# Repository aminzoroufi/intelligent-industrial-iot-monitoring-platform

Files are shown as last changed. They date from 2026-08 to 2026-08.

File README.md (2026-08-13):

# Intelligent Industrial IoT Monitoring Platform

> Implementation status: source-complete pre-release demonstrator. Software and
> synthetic evidence are `SIMULATED`; no bench or field verification is claimed.
> Native embedded builds, CAD release checks, post-fix browser evidence, CI on
> GitHub, and publication remain explicit release gates.

A retrofit condition-monitoring demonstrator for a small workshop motor, pump,
or ventilation fan. The system is designed for equipment that is currently
checked manually and where a full SCADA or predictive-maintenance suite would
be disproportionate. It combines temperature, vibration, and DC current
telemetry with offline buffering, Modbus RTU interoperability, deterministic
alarms, and an explainable Isolation Forest comparison.

The reference asset is `motor-01` at site `workshop-demo`. Seeded and simulated
measurements are always labeled as synthetic.

## Architecture

```mermaid
flowchart LR
  S["Sensors and fault fixture"] --> E["ESP32 edge gateway"]
  M["STM32 sensor node"] <-->|"RS-485 / Modbus RTU"| E
  E -->|"Wi-Fi + MQTT"| B["Mosquitto broker"]
  B --> I["Python ingestion service"]
  I --> P[("PostgreSQL")]
  P --> A["FastAPI + anomaly worker"]
  A -->|"REST + authenticated WebSocket"| W["Next.js dashboard"]
```

## Safety boundary

This is a portfolio-grade engineering demonstrator, not a certified safety
controller. Its relay output is limited to a low-voltage demonstration load.
It must not switch mains power or implement an emergency stop, personnel
protection, or unattended safety-critical shutdown. The bench procedure
requires a physical method to remove actuator power.

## Local software demo

Start the local software stack with:

```sh
cp .env.example .env
make demo
make scenario-normal
```

This starts PostgreSQL, Mosquitto, FastAPI, MQTT ingestion, a simulated gateway,
the anomaly worker, and the responsive operator dashboard at
`http://localhost:3000`. The simulated gateway publishes retained health and
safe-state command acknowledgements. ESP32 and STM32 targets, editable Wokwi
projects, Modbus PTY simulation, and the versioned per-device anomaly workflow
are implemented. Python anomaly/Modbus paths pass source and integration tests;
the embedded targets are not compiled in the available environment. The
hardware review package is editable and statically checked but intentionally
un-routed and not released for fabrication because KiCad/FreeCAD execution and
physical evidence are unavailable. Exact evidence and known limits are recorded
in the [verification report](docs/verification-report.md).

Run the local software gates with:

```sh
python -m venv .venv
.venv/bin/pip install -r requirements/ci.lock
npm --prefix web ci
make check
```

The full Compose/API smoke is `make compose-smoke` while the stack is running.
GitHub CI additionally starts a clean stack and runs the desktop/mobile
Playwright happy path.

## Engineering reports

- [English engineering report](docs/report/Intelligent_Industrial_IoT_Monitoring_Platform_EN.pdf)
- [گزارش مهندسی فارسی](docs/report/Intelligent_Industrial_IoT_Monitoring_Platform_FA.pdf)

Both PDFs are generated from editable Markdown sources, use an invariant PDF
build, and pass font/text/page rendering checks plus contact-sheet inspection.
The separate hardware connectivity PDF is marked review-only and is not a
KiCad schematic export or fabrication release.

## Repository map

| Path | Responsibility |
| --- | --- |
| `contracts/` | Versioned MQTT schemas, examples, and topic policy |
| `services/` | FastAPI, MQTT ingestion, and anomaly processes |
| `web/` | Responsive Next.js operator dashboard |
| `firmware/` | ESP32 gateway, STM32 node, shared logic, and host tests |
| `simulator/` | Telemetry, Modbus, Wokwi, and named fault scenarios |
| `hardware/` | KiCad, BOM, fabrication, model provenance, and enclosure |
| `docs/` | Architecture, operation, verification, traceability, and reports |

The dashboard workflows and security boundary are documented in
[`docs/dashboard.md`](docs/dashboard.md).

The repository does not currently include a dashboard screenshot. A previous
browser smoke was observed, but the environment did not permit a new capture
after the live-channel fix; substituting a fabricated or stale image would be
misleading. The committed Playwright flow and GitHub Compose job are the release
path for producing that evidence.

## Verification levels

- `SIMULATED`: demonstrated with host software, test fixtures, or Wokwi.
- `BENCH-VERIFIED`: executed on the documented low-voltage physical bench.
- `FIELD-VALIDATED`: evaluated on real equipment under a controlled protocol.

The current software ingestion and authenticated operations slices are
`SIMULATED`. The ESP32 path is implemented but build-blocked, not verified.
Hardware paths remain explicitly unverified unless physical evidence is
supplied.

## Known limitations and roadmap

The immediate priorities are (1) run ESP-IDF and STM32Cube target builds with
size evidence, (2) migrate and route the board in KiCad 10 and pass native
ERC/DRC before regenerating real fabrication outputs, and (3) run the complete
GitHub CI/Compose/browser flow and capture a truthful dashboard image. The
phased plan and exit criteria are in
[roadmap and limitations](docs/roadmap-and-limitations.md).

## Author and license

Copyright (c) 2026 Amin Zoroufi <aminn.zoroufi@gmail.com>

Source is visible for portfolio inspection under the custom
[Portfolio Source-Available License](LICENSE.md). This is not an open-source
license and it is marked for legal review.

Locked runtime dependency attribution is recorded in the
[dependency/license inventory](docs/dependency-license-inventory.csv).

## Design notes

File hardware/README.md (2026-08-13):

# Hardware design status

Revision `A0-UNVERIFIED` is an editable engineering review package for the
extra-low-voltage demonstrator. It is not fabrication-ready. Do not order a PCB,
assemble it, or connect a load from these files until the review gates in
`fabrication/fabrication-status.json` are completed and independently checked.

The canonical, machine-readable source is `design.json`. It records the board
envelope, selected manufacturer part numbers, ratings, placement, pin/net
intent, safety policy, and which 3D shapes are dimensional engineering envelopes
rather than official component models. Run:

```sh
.venv/bin/python scripts/generate_hardware_artifacts.py
.venv/bin/python scripts/generate_hardware_artifacts.py --check
```

The generator creates the BOM, placement, editable KiCad review sources,
mechanical envelopes, FreeCAD rebuild macro, preview SVGs, and review-only
fabrication files. The generation check verifies metadata and model checksums;
it does not substitute for electrical or layout verification.

## Circuit intent

- 5 V SELV/PELV input through resettable overcurrent, polarity, transient, and
  bulk-decoupling stages;
- AP2112K 3.3 V rail with local bulk and high-frequency decoupling;
- ESP32-WROOM-32E gateway with explicit enable/boot bias and UART header;
- TMP117 temperature, INA219 high-side current, 50 mΩ/1 W shunt, and ADXL345
  SPI vibration sensor with interrupt;
- MAX3485 3.3 V half-duplex RS-485, SM712 clamp, selectable 120 Ω termination,
  optional 680 Ω bias, ground reference, and bus test points;
- AO3400A low-side 5 V relay-coil driver, gate resistor/pull-down, and SS14
  flyback diode;
- relay COM/NO connector restricted by project policy to 30 VDC and 2 A. It
  must never switch mains, implement an emergency stop, or control a hazardous
  load.

## KiCad boundary

`iiot-monitor.kicad_pcb` is an editable KiCad board review placement. The
schematic is deliberately retained in KiCad legacy v4 form with a project cache
library because `kicad-cli` is unavailable here; KiCad 10 must import and save it
as `.kicad_sch`. The board is un-routed. Custom review footprints and every pin
mapping must be replaced or verified against current official datasheets and
manufacturer land patterns.

The checked-in ERC/DRC reports say `NOT RUN` and are not passes. The Gerber-like
review set contains outline/status geometry only; copper production geometry is
intentionally absent. After schematic migration, symbol/footprint review,
routing, and actual zero-unexplained-violation ERC/DRC, regenerate outputs with
KiCad 10.0.4 and replace the reports with raw tool output.

## Mechanical and provenance boundary

The project-authored ESP32 and relay STEP files are only datasheet-sized
engineering envelopes. They are visibly named `-envelope`, recorded with source
URL and checksum in `model-provenance.csv`, and must not be described as vendor
3D models. The board assembly STEP is likewise a placement/clearance envelope,
not a KiCad component-accurate export.

`enclosure/iiot-enclosure.FCMacro` is the editable FreeCAD rebuild source.
Project-generated STEP/STL review geometry uses the same board-derived
dimensions. FreeCAD is unavailable in the current environment, so no `.FCStd`
save or FreeCAD-vs-export comparison is claimed.

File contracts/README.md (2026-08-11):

# MQTT contracts

All application topics use this root:

```text
iiot/v1/{site_id}/{device_id}/telemetry
iiot/v1/{site_id}/{device_id}/health
iiot/v1/{site_id}/{device_id}/events
iiot/v1/{site_id}/{device_id}/commands
iiot/v1/{site_id}/{device_id}/command-acks
iiot/v1/{site_id}/{device_id}/availability
```

`site_id` and `device_id` must match `^[a-z0-9][a-z0-9-]{0,62}$`. Payloads are
UTF-8 JSON and must not exceed 16 KiB. Unknown schema versions, malformed JSON,
oversized payloads, topic/payload identity mismatches, non-finite numbers, and
unknown command kinds are rejected, counted, and recorded without logging
secrets or the complete offending payload.

| Suffix | QoS | Retained | Notes |
| --- | ---: | --- | --- |
| telemetry | 1 | no | duplicates removed by globally unique `message_id` |
| health | 1 | yes | latest bounded snapshot; never contains credentials |
| events | 1 | no | state changes and diagnostics |
| commands | 1 | no | authenticated server origin, short expiry |
| command-acks | 1 | no | one acknowledgement per command attempt |
| availability | 1 | yes | LWT publishes `offline`; successful boot publishes `online` |

## Time and ordering

Timestamps are RFC 3339 UTC. When the device clock is not synchronized,
`device_time` is `null`, `clock_synchronized` is false, and backend receipt time
is the display fallback. The monotonic `sequence` orders messages from one
device across a configuration-preserving reboot. `uptime_ms` may reset and reset
reason is reported in health. No order is assumed across different MQTT topics.

During disconnection, the gateway retains a bounded durable telemetry ring.
Replay is oldest-first with the original `message_id`, `sequence`, and
`device_time`; `replayed` becomes true. If capacity is exhausted, the oldest
telemetry record is dropped, `dropped_message_count` increments, and local
threshold monitoring continues. This deterministic policy preserves the newest
condition evidence while making loss visible.

## Compatibility

Additive optional fields are allowed within version 1. Removing a field,
changing a unit or meaning, relaxing an identity boundary, or changing field
type requires a new schema and topic major version. Consumers ignore unknown
optional properties only when the schema permits them; these schemas otherwise
use `additionalProperties: false` to catch accidental drift.

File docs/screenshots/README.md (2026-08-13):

# Screenshot evidence policy

Only screenshots captured from the running committed application with clearly
labeled synthetic data belong here. Do not add mockups, design-tool renders,
stale pages from an earlier build, or images whose source commit and scenario
cannot be identified.

The release screenshot is pending because the browser rerun after the live
loopback/cookie fix has not executed. The CI Playwright job must first pass the
desktop and mobile operator flow against a clean Compose build. Then capture the
fleet and device-detail views, record the source commit and named simulator
scenario in the image caption or adjacent Markdown, inspect for exposed tokens
or personal data, and add the real image to the README.

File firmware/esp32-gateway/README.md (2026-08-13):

# ESP32 edge gateway

The gateway targets an ESP32-DevKitC V4 with ESP-IDF 6.0.2. It is organized as
fixed-responsibility FreeRTOS tasks around the dependency-free shared C core.
The relay output is for an extra-low-voltage demonstration load only and is OFF
before NVS, networking, or command processing begins.

## Responsibilities and timing

| Responsibility | Implementation | Default behavior |
| --- | --- | --- |
| sampling | high-priority static task | 100 ms period with `vTaskDelayUntil` |
| vibration interrupt | GPIO ISR to task notification | ISR performs no bus work |
| aggregation | static task and `iiot_sample_window_t` | 1 s mean/RMS/peak/crest window |
| local alarms | shared hysteresis state machine | continues without a network |
| communication | MQTT QoS 1 and durable replay | oldest queued record first |
| storage | NVS config, slot records, metadata CRC | 32 records by default |
| commands | bounded MQTT input queue | identity/expiry/type/range validated |
| health | retained MQTT snapshot | every 10 seconds |
| watchdog | ESP task watchdog | sampling/aggregation/communication enrolled |

The ADXL345 data-ready ISR only notifies the sampling task. TMP117 and INA219
share a 400 kHz I2C bus; ADXL345 uses 5 MHz SPI mode 3. A UART in hardware
half-duplex RS-485 mode polls the focused STM32 node. All measurement fields use
the SI units encoded in the version-1 contracts.

## Pin map

| Function | ESP32 GPIO | Direction / interface | Electrical note |
| --- | ---: | --- | --- |
| TMP117 + INA219 SDA | 21 | I2C bidirectional | 3.3 V pull-ups |
| TMP117 + INA219 SCL | 22 | I2C output | 3.3 V pull-ups |
| ADXL345 MOSI / MISO / SCLK | 23 / 19 / 18 | SPI | 3.3 V only |
| ADXL345 chip select | 5 | output | pull high at reset |
| ADXL345 data ready | 34 | interrupt input | input-only GPIO |
| RS-485 TX / RX / DE | 17 / 16 / 25 | UART half duplex | MAX3485-class 3.3 V transceiver |
| demo relay driver | 27 | output | transistor + flyback; low-voltage load only |
| status LED | 2 | output | board-dependent active level |
| provision / reset | 0 | pulled-up input | 10 s boot hold required for erase |

GPIO0 is a strapping pin. Production hardware must keep its pull-up and button
network compatible with normal boot and make the ten-second reset action
deliberate.

## Configuration and provisioning

The NVS blob has a magic value, schema version, structure size, generation, and
CRC-32. Version 0 has an explicit migration function in the shared core. An
invalid blob loads conservative defaults, raises `CONFIG_FALLBACK`, and keeps
the relay OFF. Unprovisioned firmware exposes only a 120-second serial setup
window. Commands are `SHOW`, `SET field=value`, `COMMIT`, and `ABORT`; secret
values are masked in device responses. See `docs/provisioning.md` for the
operator sequence.

NVS does not by itself make stored Wi-Fi credentials confidential. Enable ESP32
Secure Boot, flash encryption, and NVS encryption with per-device provisioning
for any deployment outside the isolated demonstration.

## Offline queue and sequence durability

Payload records occupy separate NVS keys and compact metadata carries a CRC.
One enqueue writes one slot plus metadata, allowing NVS wear levelling to avoid
rewriting a monolithic queue blob. At capacity, the oldest record is replaced,
the dropped counter increments, and `OFFLINE_QUEUE_DROP` remains visible.
Reconnect replays oldest first with the original UUID and sequence and sets
`replayed=true`; a crash between publish and removal can duplicate a message,
which the backend removes by UUID.

Sequence numbers are reserved in NVS blocks of 256. A reboot can create a gap,
but cannot move the sequence backwards, and avoids a flash commit every second.
This remains a bounded demonstration design; the actual write lifetime needs a
bench workload and flash-vendor endurance calculation.

## Build and host tests

```sh
cd firmware/esp32-gateway
idf.py set-target esp32
idf.py build

cmake -S firmware/host-tests -B firmware/host-tests/build
cmake --build firmware/host-tests/build --parallel
ctest --test-dir firmware/host-tests/build --output-on-failure
```

No target or host C build is marked as passed yet because the available macOS
compiler is blocked by its system Xcode license and ESP-IDF is not installed.
The Linux CI workflow must execute these commands before the milestone can move
from implemented to verified.

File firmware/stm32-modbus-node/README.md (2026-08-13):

# STM32 Modbus RTU sensor node

This focused node targets the STM32F103C8T6 Blue Pill supported by Wokwi. It
does not duplicate gateway networking or storage. A timer schedules a
deterministic ADC fixture, USART2 serves the versioned Modbus RTU map through a
MAX3485-class transceiver, and the independent watchdog covers main-loop
stalls. The implementation uses STM32CubeF1 1.8.6 HAL sources from an external,
exact-version checkout rather than copying vendor code into this repository.

## Build

```sh
git clone --recursive --depth 1 --branch v1.8.6 \
  https://github.com/STMicroelectronics/STM32CubeF1.git /path/to/STM32CubeF1
export STM32CUBE_F1_PATH=/path/to/STM32CubeF1
cmake -S firmware/stm32-modbus-node -B firmware/stm32-modbus-node/build \
  -DCMAKE_TOOLCHAIN_FILE=cmake/arm-none-eabi.cmake
cmake --build firmware/stm32-modbus-node/build --parallel
```

The build emits ELF, HEX, BIN, linker map, and an `arm-none-eabi-size` report.
The compiler, CMake, and STM32Cube checkout are unavailable in the current
environment, so none of those outputs or a target build pass is claimed.

## Timing and fault path

TIM3 interrupts at 10 Hz and only marks a sample due. ADC conversion and
calibration execute in the main loop. USART2 uses 115200 baud, 8 data bits,
even parity, and 1 stop bit; receive-to-idle interrupts hand an eight-byte frame
to the main loop. CRC, address, function, range, and value checks happen in the
same dependency-free core exercised by host tests. Incomplete frames are
discarded and reported as a UART fault.

The ADC fixture maps 0–3.3 V to 20.00–100.00 °C before signed offset and Q15 gain
calibration. Readings within ten ADC counts of a rail are marked out of range.
A missing 500 ms sampling deadline raises `SAMPLE_STALE`. The physical build
refreshes a roughly two-second independent watchdog; Wokwi builds explicitly
disable IWDG because that peripheral is not modeled by the simulator.

Configuration occupies the final 1 KiB flash page and carries a magic value,
schema version, structure size, generation, limits, and CRC-32. Writes erase
and verify that one page. An interrupted write loads safe defaults and exposes
the configuration-fallback fault. Reset count uses the backup domain when
available and is explicitly reduced to a simulated value in Wokwi.

## Wiring

| Function | STM32 pin | MAX3485 / fixture connection | Note |
| --- | --- | --- | --- |
| fixture input | PA0 / ADC1_IN0 | 0–3.3 V potentiometer or conditioned sensor | never exceed MCU rails |
| Modbus TX | PA2 / USART2_TX | DI | 3.3 V logic |
| Modbus RX | PA3 / USART2_RX | RO | 3.3 V logic |
| driver enable | PB1 | DE and active-high `/RE` control | receiver disabled while sending |
| status LED | PC13 | onboard LED | active low on common Blue Pill boards |
| SWD | PA13 / PA14 | SWDIO / SWCLK | retain for recovery/debug |

Place 120 Ω termination only at each physical bus end, not every node. Fit one
known bias network for the whole bus, provide a shared reference conductor,
and add connector-side surge/ESD protection appropriate to the installation.
This is a 3.3 V, low-voltage demonstration and is not an isolated industrial
interface until a documented isolated transceiver/power design is used.

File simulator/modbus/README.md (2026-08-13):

# Modbus RTU pseudo-terminal simulator

The simulator exposes the version-1 STM32 register contract through a POSIX
pseudo-terminal pair. The printed slave path can be opened by a host Modbus
master at 115200 baud, 8 data bits, even parity, and 1 stop bit.

```sh
python -m simulator.modbus.pty_node --scenario normal
python -m simulator.modbus.pty_node --scenario timeout
python -m simulator.modbus.pty_node --scenario bad-crc
python -m simulator.modbus.pty_node --scenario illegal-address
python -m simulator.modbus.pty_node --scenario stale
```

The protocol model is deterministic and its first-eight-register response is
the same golden byte frame asserted by the shared C tests. A pseudo-terminal
models byte transport only; it cannot verify MAX3485 voltage levels, driver
enable timing, line bias, termination, common-mode range, reflections, or EMC.

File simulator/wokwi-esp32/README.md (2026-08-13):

# ESP32 Wokwi path

This project selects the ESP32-DevKitC V4 supported by Wokwi and runs the same
gateway tasks and shared C core as the production build. Exact TMP117, INA219,
ADXL345, and RS-485 electrical behavior is not claimed: `CONFIG_IIOT_SIMULATION`
selects a deterministic adapter at the driver boundary while the real register
drivers remain in the source tree.

## Build

With ESP-IDF 6.0.2 exported in the shell:

```sh
cd firmware/esp32-gateway
idf.py set-target esp32
SDKCONFIG_DEFAULTS="sdkconfig.defaults;sdkconfig.simulation" idf.py build
```

Open `simulator/wokwi-esp32/diagram.json` with the Wokwi extension. On first
boot, use the serial console before its 120-second deadline:

```text
SET wifi_ssid=Wokwi-GUEST
SET wifi_password=
SET mqtt_host=host.wokwi.internal
SET mqtt_port=1883
COMMIT
```

`host.wokwi.internal` is appropriate only when the Wokwi environment can reach
a broker forwarded from the development host. Do not point the command topic at
an unauthenticated public broker. The serial flow masks password values in its
responses.

After reboot, each short press of **NEXT SYNTHETIC FAULT** advances through
normal, rising temperature, vibration increase, current overload, temperature
driver failure, and Modbus timeout, then returns to normal. Values are formula
driven, not random. Holding that GPIO during boot for ten seconds intentionally
factory-resets NVS, so do not hold it while resetting unless erasure is desired.

No Wokwi execution is claimed in the current verification report: ESP-IDF and
the Wokwi runner were unavailable in the implementation environment. In
particular, simulator timing, Wi-Fi/RF behavior, flash wear, analog fidelity,
and RS-485 electrical behavior remain unverified by Wokwi.

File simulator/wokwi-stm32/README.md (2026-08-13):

# STM32 Wokwi path

The Blue Pill simulation exercises the 10 Hz timer, ADC fixture, GPIO, USART2,
and shared Modbus state. Build it with:

```sh
export STM32CUBE_F1_PATH=/path/to/STM32CubeF1-v1.8.6
cmake -S firmware/stm32-modbus-node \
  -B firmware/stm32-modbus-node/build-wokwi \
  -DCMAKE_TOOLCHAIN_FILE=cmake/arm-none-eabi.cmake \
  -DIIOT_WOKWI=ON
cmake --build firmware/stm32-modbus-node/build-wokwi --parallel
```

The potentiometer defaults to ADC count 2048 and the logic analyzer observes
USART2 TX, RX, and driver enable. Wokwi documents ADC1 as partial and does not
model the independent watchdog, power controller, RTC/backup domain, MAX3485
electrical layer, line termination, or biasing. The Wokwi build therefore
disables IWDG and uses a simulated reset count; these omissions are explicit.

No Wokwi execution or serial trace is claimed because the runner and ARM
toolchain are unavailable in the current environment.

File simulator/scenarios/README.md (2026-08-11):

# Deterministic scenarios

All scenarios are synthetic and use a fixed pseudo-random seed. `normal` keeps
signals inside the reference envelope. The other named scenarios introduce one
controlled change at a time: temperature ramp, vibration growth, current ramp,
or a stuck temperature value. These are reproducibility fixtures, not evidence
of field performance or mechanical root cause.

Run a scenario against the local broker with:

```sh
.venv/bin/python -m simulator.telemetry_generator.main normal
```

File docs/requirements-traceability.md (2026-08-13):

# Requirements traceability

Status values are `DESIGNED`, `IMPLEMENTED`, `VERIFIED`, and `BLOCKED`. A design
entry is not evidence that a requirement works.

| ID | Requirement | Code / artifact | Verification | Documentation | Status |
| --- | --- | --- | --- | --- | --- |
| SYS-001 | End-to-end MQTT condition telemetry | `contracts/`, `services/`, `web/` | Backend Compose passed; dashboard sign-in/fleet smoke passed; post-fix live browser run blocked | `docs/system-overview.md`, `docs/dashboard.md` | IMPLEMENTED |
| SYS-002 | Safe low-voltage relay command | command schema, API command service, simulated gateway | unit tests plus live ON/OFF MQTT acknowledgements | `docs/safety.md`, `docs/operations-workflows.md` | VERIFIED |
| DAT-001 | Versioned SI-unit telemetry envelope | `contracts/schemas/telemetry.v1.schema.json` | `tests/test_contracts.py` (8 passing) | `contracts/README.md` | VERIFIED |
| DAT-002 | Idempotent ordered replay | `services/api/app/ingestion.py` | unit collision tests and identical Compose batch replay | `contracts/README.md` | VERIFIED |
| ESP-001 | Sensor sampling and aggregation | `firmware/esp32-gateway/`, `firmware/shared/` | C host tests authored; local compiler blocked | `firmware/esp32-gateway/README.md` | IMPLEMENTED |
| ESP-002 | Bounded durable offline queue | NVS slot journal and shared ring core | queue/loss/replay tests authored; local compiler blocked; power interruption unverified | `docs/offline-behavior.md` | IMPLEMENTED |
| STM-001 | Versioned Modbus RTU node | STM32 HAL target plus shared C protocol and PTY simulator | 5 Python PTY/protocol tests pass; C golden/target builds blocked | `docs/modbus-register-map.md`, `firmware/stm32-modbus-node/README.md` | IMPLEMENTED |
| API-001 | JWT authentication and authorization | `services/api/` | auth tests and authenticated Compose query | API OpenAPI schema | VERIFIED |
| API-002 | Device, alarm, calibration, maintenance APIs | `services/api/` | REST integration tests and Compose workflow | OpenAPI and `docs/operations-workflows.md` | VERIFIED |
| UI-001 | Accessible responsive operator workflows | `web/` | ESLint, TypeScript, 4 component tests, production build, partial browser smoke | `docs/dashboard.md` | IMPLEMENTED |
| ML-001 | Explainable per-device Isolation Forest | `services/anomaly_worker/`, model registry/API, dashboard comparison | 8 causal-feature, artifact, evaluation, registry, scoring, and fallback tests pass | `docs/anomaly-detection.md` | VERIFIED |
| HW-001 | Editable KiCad design and fabrication outputs | canonical design, KiCad review source, BOM, placement, mechanical/provenance sources | 5 static consistency/provenance/release-safety tests pass; ERC/DRC and routing blocked | `hardware/README.md`, `docs/hardware-in-the-loop.md` | IMPLEMENTED |
| SIM-001 | Reproducible named software faults | telemetry generator, Wokwi projects, Modbus PTY | Python scenario/Modbus tests; target Wokwi runs blocked | simulator READMEs and verification report | IMPLEMENTED |
| DOC-001 | English and Persian reproducible PDFs | editable sources, invariant report generator, bundled fonts | both 18-page reports and 4-page hardware review render on every page; contact sheets visually inspected | `docs/report/README.md` | VERIFIED |
| CI-001 | Credential-free hosted quality/security gates | `.github/workflows/`, Dependabot config | YAML, action-pin, command, and hygiene inspection pass; hosted execution awaits publication | `docs/ci.md` | IMPLEMENTED |
| LIC-001 | Dependency attribution and incompatible-license gate | runtime/CI locks, npm lock, Python policy, generated inventory | 602 exact rows; missing/unknown/strong-copyleft policy guards pass | `THIRD_PARTY_NOTICES.md`, `docs/ci.md` | VERIFIED |
| PROV-001 | Binary/CAD asset provenance | model and dashboard-font provenance plus license files | checksum, license, release-guard, and source checks pass | `hardware/README.md`, `THIRD_PARTY_NOTICES.md` | VERIFIED |
| SEC-001 | Secrets, malformed input, replay, CSV, WS threat controls | contracts, services, dashboard BFF, ESP32 command/config paths | validation, authorization, replay, CSV, credential-safe WS tests; ESP32 tests build-blocked | `SECURITY.md`, `docs/operations-workflows.md`, `docs/provisioning.md` | IMPLEMENTED |

This table is updated at every milestone. `VERIFIED` requires a corresponding
passing row in `docs/verification-report.md`.

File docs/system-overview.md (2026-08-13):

# System overview

## Problem and users

Workshop maintainers often inspect small motors, pumps, and fans manually. A
bearing problem, overload, blocked cooling path, or failed sensor can emerge
between inspections. The demonstrator provides maintainers with continuous
condition signals without pretending to replace a certified safety system.

Primary stakeholders are a maintenance operator, a calibration technician, a
system administrator, and an engineer evaluating retrofit feasibility.

## Scope

- one ESP32 gateway for temperature, vibration, DC current, local thresholds,
  bounded buffering, MQTT, and a low-voltage demo actuator;
- one focused STM32 sensor node exposing a versioned Modbus RTU register map;
- separate ingestion, API, and anomaly processes backed by PostgreSQL;
- an authenticated browser UI for live condition, alarms, calibration,
  maintenance, export, and detector comparison;
- deterministic host simulation and named fault scenarios.

## Non-goals

- certified protection, emergency stop, or direct mains switching;
- diagnosis of a specific mechanical root cause from synthetic data;
- high-availability cloud operations or multi-tenant billing;
- claiming simulated performance as field performance.

## Success criteria

Success means the seeded MQTT-to-dashboard path is reproducible from a clean
clone; replay is idempotent; alarm and command actions are authenticated and
audited; firmware calculations and Modbus frames are host-tested; anomaly
results are reproducible and explained by observed features; and all remaining
hardware gaps are visible in the verification report.

## System context

```mermaid
flowchart LR
  O["Maintenance operator"] -->|"condition, alarms, records, safe demo command"| P["Monitoring platform"]
  T["Calibration technician"] -->|"calibration evidence"| P
  A["Administrator"] -->|"identity and configuration"| P
  P -->|"temperature, current, vibration"| D["Low-voltage demo asset"]
  P <-->|"legacy register exchange"| L["STM32 Modbus node"]
```

## Container view

```mermaid
flowchart LR
  G["ESP32 or simulated gateway"] -->|"MQTT QoS 1"| M["Mosquitto"]
  M --> I["MQTT ingestor"]
  I --> DB[("PostgreSQL")]
  DB --> ML["Anomaly worker"]
  DB --> API["FastAPI"]
  API -->|"REST + authenticated WebSocket"| UI["Next.js dashboard"]
  UI --> OP["Operator browser"]
```

## Local deployment

```mermaid
flowchart TB
  subgraph H["Developer host"]
    subgraph C["Docker Compose project: iiot-monitoring-demo"]
      PG["postgres:18.3-bookworm"]
      MQ["eclipse-mosquitto:2.1.2-alpine"]
      PY["API / ingestor / anomaly / simulated gateway"]
      WEB["Node 24 / Next.js standalone"]
    end
    B["Browser"] -->|"localhost:3000"| WEB
    WEB -->|"internal HTTP"| PY
    PY <--> PG
    PY <--> MQ
  end
```

Exact tags are selected for reproducibility but are not yet digest-pinned. The
Compose network uses public development credentials and plain MQTT only inside
the local demonstrator boundary.

## Telemetry and live-update sequence

```mermaid
sequenceDiagram
  participant G as Gateway
  participant M as Mosquitto
  participant I as Ingestor
  participant P as PostgreSQL
  participant A as FastAPI
  participant W as Browser
  G->>M: QoS 1 telemetry envelope
  M->>I: deliver topic + payload
  I->>A: bounded internal ingest request
  A->>P: validate and insert or deduplicate
  P-->>A: NOTIFY telemetry event
  A-->>W: authenticated WebSocket update
  W->>A: bounded history request
  A->>P: ordered range query
  P-->>A: persisted rows
  A-->>W: SI-unit telemetry page
```

## Safe relay-command sequence

```mermaid
sequenceDiagram
  participant O as Operator
  participant A as FastAPI
  participant P as PostgreSQL
  participant M as Mosquitto
  participant G as Gateway
  O->>A: authenticated relay request + timeout
  A->>P: audit accepted command
  A->>M: publish device-scoped command
  M->>G: QoS 1 command
  G->>G: validate ID, target, expiry, safe policy
  G->>M: acknowledgement with resulting state
  M->>A: command acknowledgement
  A->>P: durable completion/rejection audit
  A-->>O: live status; relay auto-clears OFF
```

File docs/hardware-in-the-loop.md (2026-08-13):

# Low-voltage hardware-in-the-loop procedure

Status: not executed; no physical hardware was supplied.

This procedure applies only after a reviewed PCB revision has passed ERC, DRC,
assembly inspection, continuity checks, and a current-limited power-up. Revision
`A0-UNVERIFIED` is not eligible.

## Equipment and boundary

- isolated 5 V laboratory supply with adjustable current limit and physical
  output switch;
- oscilloscope, DMM, logic analyzer, and USB-to-3.3 V UART adapter;
- protected low-voltage DC demo load and independent fuse;
- second RS-485 node or isolated USB/RS-485 adapter;
- vibration fixture that cannot eject parts and temperature reference that stays
  within component and handling limits.

Never connect mains. The relay is not an emergency stop, interlock, protective
device, or permission to energize equipment. Keep a physical means to remove
actuator power.

## Ordered checks

1. Inspect polarity, shorts, component orientation, shunt, TVS, flyback diode,
   relay isolation distance, and connector labels with power removed.
2. Measure input-to-ground resistance. Power at 5 V with a 100 mA current limit,
   then raise the limit only after the 3.3 V rail is stable and no part heats.
3. Record 5 V/3.3 V rail min/max during ESP32 Wi-Fi association and relay
   switching; inspect reset reason and brownout counters.
4. Compare TMP117 readings with a traceable reference at three safe points.
   Record raw, previous, and updated calibration coefficients.
5. Apply known DC current through the shunt at zero and at least three load
   points below 2 A. Compare DMM and INA219 values without exceeding shunt power.
6. Check ADXL345 identity, data-ready interrupt rate, stationary noise, axis
   orientation, and response on the guarded vibration fixture.
7. Inspect RS-485 A/B waveforms and DE timing with termination disabled and then
   enabled only at the two bus ends. Exercise valid, CRC-error, exception,
   timeout, and disconnected-node cases.
8. Drive only the fused low-voltage demo relay load. Verify default OFF, command
   expiry, bounded auto-off, flyback behavior, reboot safe state, and MQTT
   acknowledgement for ON/OFF.
9. Disconnect network access long enough to fill/replay the documented queue;
   power-cycle at controlled journal points and check ordering/loss counters.
10. Inject the named firmware scenarios, task stall, and repeated reset. Confirm
    watchdog recovery does not create a reboot loop.

For every run, retain board revision/serial, firmware SHA, equipment IDs,
calibration dates, setup photo, raw measurements, expected tolerances, result,
operator, UTC time, and anomalies. Only actual retained evidence may change a
verification level to `BENCH-VERIFIED`.

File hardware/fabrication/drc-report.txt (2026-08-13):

Status: NOT RUN
Tool: kicad-cli 10.0.4
Reason: tool is unavailable in the execution environment.
This file is not a passing report and must be replaced by actual tool output.

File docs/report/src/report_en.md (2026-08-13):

# Intelligent Industrial IoT Monitoring Platform

Author: Amin Zoroufi
Email: aminn.zoroufi@gmail.com
Configured repository: https://github.com/aminzoroufi/intelligent-industrial-iot-monitoring-platform
Version: 0.1.0
Date: 12 August 2026
Copyright: Copyright 2026 Amin Zoroufi
Verification level: SIMULATED - no bench or field validation is claimed
License: Portfolio Source-Available; custom text remains marked for legal review

## 1. Executive summary

This portfolio system demonstrates continuous condition monitoring for a small workshop motor, pump, or fan. It combines temperature, vibration, and DC current measurements with bounded offline buffering, MQTT transport, PostgreSQL persistence, authenticated operator workflows, Modbus RTU interoperability, and an intentionally modest Isolation Forest comparison detector.

The implementation is evidence-led. Forty-seven Python tests pass after the hardware static checks are included, the dashboard passes lint, strict TypeScript, and four component tests, and a live Compose backend slice previously exercised MQTT ingestion, replay, authentication, WebSocket delivery, alarms, and safe simulated relay acknowledgements. Embedded target builds, current CAD ERC/DRC, post-change Compose execution, physical bench behavior, and field performance remain explicitly unverified.

## 2. Maintenance problem and product rationale

Small workshops often inspect motors and fans manually. Bearing degradation, overload, blocked cooling, loose connections, or a failed sensor can develop between rounds. A full SCADA or predictive-maintenance suite can be disproportionate for one low-value asset, while unreliable connectivity makes a cloud-only design fragile.

The project was chosen because it crosses embedded timing, industrial protocols, backend integrity, operator experience, electronics, and honest data analysis without requiring invented customer claims. The reference asset is the clearly simulated motor-01 at workshop-demo. The intended value is earlier, better documented maintenance attention, not automatic diagnosis or safety shutdown.

## 3. Stakeholders, scope, safety, and success

Stakeholders are the maintenance operator, calibration technician, administrator, and engineer evaluating retrofit feasibility. Use cases include live status, alarm acknowledgement, calibration history, maintenance records, bounded export, offline replay, and comparison of deterministic and statistical detection.

- In scope: one ESP32 gateway, one focused STM32 Modbus node, sensors, a low-voltage demo relay, local Compose services, simulation, and editable engineering sources.
- Out of scope: mains switching, emergency-stop functions, certified protection, autonomous hazardous control, customer deployment, high availability, and field-validated predictive claims.
- Success means reproducible data contracts, idempotent replay, authenticated and audited mutations, explicit health/fault state, host-tested logic, and visible verification gaps.

## 4. Architecture and end-to-end data flow

[[ARCHITECTURE]]

Sensors feed the ESP32 through I2C, SPI with a data-ready interrupt, current measurement, and a UART-controlled MAX3485-class RS-485 interface. The gateway validates, aggregates, sequences, and queues telemetry before publishing versioned MQTT envelopes. A dedicated ingestor validates topic identity and JSON Schema before one transaction persists device state, telemetry, and threshold alarms.

FastAPI exposes authenticated REST and origin-checked WebSockets. PostgreSQL LISTEN/NOTIFY crosses process boundaries without turning the API into the ingestion path. The Next.js dashboard uses a same-origin backend-for-frontend for REST and an HttpOnly cookie for browser WebSocket authentication.

## 5. ESP32 gateway, sensors, and real-time behavior

The ESP-IDF 6.0.2 source separates production drivers from shared C logic. TMP117 and INA219 use I2C; ADXL345 uses SPI and data-ready signaling; RS-485 uses explicit driver-enable timing; a deterministic Wokwi adapter replaces only the driver boundary. FreeRTOS tasks cover acquisition, aggregation, MQTT, commands, health, and fault supervision.

Shared host logic implements configuration magic/schema/generation/CRC, migration and safe defaults, RMS/peak/crest calculations, sample-quality accounting, threshold hysteresis, bounded oldest-drop buffering, topics, serialization, and exponential reconnect with jitter. NVS uses per-slot records plus a pending journal and reserved sequence ranges to survive interruption without silent ordering ambiguity.

The relay defaults OFF, validates device and expiry, auto-clears after a bounded interval, and reports acknowledgement state. Watchdog and reboot-loop guards report reset reasons rather than hiding repeated failure. Target compilation is not claimed because ESP-IDF and a usable host C toolchain were unavailable.

## 6. STM32 node and Modbus RTU

The STM32F103C8T6-class node uses STM32CubeF1 HAL design intent: TIM3 triggers a 10 Hz acquisition fixture, ADC values update a versioned 18-register map, USART2 runs 115200 8E1, and RS-485 DE is explicit. Function 0x03 reads registers; bounded 0x06 writes update permitted configuration and persist a CRC-protected record in the final flash page.

Illegal function, address, value, CRC, timeout, and stale-data cases have explicit outcomes. A watchdog, backup-domain reset count, and fault flags keep operational state inspectable. Five Python tests verify golden bytes, request/response CRC, exception frames, stale registers, timeout, and a pseudo-terminal round trip. The shared C golden tests and ARM target remain build-blocked.

## 7. Provisioning, connectivity, queue, and health

Provisioning is intentionally local: serial commands accept bounded configuration, secrets are never returned, and factory reset requires a deliberate multi-step sequence. Wi-Fi and MQTT reconnect use bounded exponential backoff with jitter. MQTT topics include site, device, and message kind; telemetry uses QoS 1, retained health reports liveness, and LWT marks unexpected disconnects.

When the broker is unavailable, a finite flash queue records exact capacity, depth, dropped-message count, and replay flag. The oldest entry is dropped only when capacity is exhausted, and replay preserves stored order. Clock-unsynchronized samples carry null device time and uptime rather than fabricated UTC. Heartbeats expose RSSI, reset reason/count, firmware, queue state, Modbus state, and active faults.

## 8. Backend data, APIs, authentication, and audit

PostgreSQL stores users, devices, thresholds, telemetry, health snapshots, alarms, calibration, maintenance, commands, audit events, error logs, and anomaly-model registry metadata. Device message ID and device-sequence uniqueness make duplicate delivery idempotent while rejecting conflicting reuse. Monotonic sequence and uptime fields are 64-bit.

FastAPI validates bounded time ranges and payloads, returns explicit errors, escapes CSV formula prefixes, and never leaks artifact paths or secrets. OAuth2 password login issues short-lived audience-bound JWTs. Admin-only mutations create audit events. Browser WebSockets require an exact configured Origin and an HttpOnly cookie; command-line clients use a bearer subprotocol rather than query-string tokens.

## 9. Dashboard and maintenance workflows

The responsive Next.js 16 dashboard provides fleet status, device health, bounded/gapped telemetry charts with SI units and threshold overlays, alarm history and acknowledgement, calibration, maintenance, threshold configuration, CSV export, relay command state, and an About/legal screen. Initial independent requests run in Server Components; interactive controls remain small Client Components.

The detector-comparison route obtains model readiness from the database registry. It separates threshold, sensor-rule, and anomaly sources, reports not-ready/stale/error states, shows model version and training counts, and labels all evaluation metrics synthetic. The production build and browser sign-in/fleet smoke passed before a loopback live-channel fix; the required rebuilt browser rerun was denied, so that exact path remains blocked.

## 10. Anomaly model and honest interpretation

[[DETECTION_METRICS]]

Per-device feature schema version 1 uses a causal trailing window: temperature level/slope/variation, current mean/variation, vibration RMS mean, peak maximum, crest mean, and vibration/current ratio. Training accepts only explicitly selected good-quality, fault-free healthy windows, splits chronologically, fixes seed 20260811, and records schema, library version, interval, counts, policy, and SHA-256 checksum.

The persisted score is the negative of Isolation Forest score_samples, so higher means more anomalous. The percentile is an empirical rank against healthy validation scores, not probability. Reasons cite observed values and healthy 1st/99th percentiles without claiming root cause. Missing, stuck, noisy, impossible, inconsistent, or too-fast sensor values remain deterministic rules.

The seeded report gives model F1 0.7293 and false-positive rate 0.0545; deterministic threshold-plus-sensor F1 is 0.6787 with false-positive rate 0.0. These fixture results cannot be generalized to real equipment.

## 11. Simulation and exact reproduction

The telemetry generator has deterministic normal, rising-temperature, vibration-imbalance, current-overload, and stuck-sensor scenarios. Wokwi projects bind the ESP32 and STM32 production boundaries where supported; the Modbus PTY simulator provides host protocol execution without an electrical bus. Simulator gaps include RF, analog accuracy, interrupt jitter, flash wear, brownout physics, and RS-485 signal integrity.

- Copy .env.example to .env, then run docker compose up --build -d.
- Publish a named scenario with python -m simulator.telemetry_generator.main normal.
- Run Python gates with pytest, Ruff, and strict MyPy; run dashboard lint, typecheck, tests, and build separately.
- Regenerate detector evidence with python -m services.anomaly_worker.main evaluate-demo.

## 12. Schematic, PCB, BOM, models, and enclosure

[[BOARD]]

Hardware revision A0-UNVERIFIED is a review package, not a fabrication release. The canonical design selects ESP32-WROOM-32E, TMP117, INA219 with a 50 mOhm 1 W shunt, ADXL345, MAX3485 with optional 120 ohm termination and 680 ohm bias, SM712 bus protection, AP2112K regulation, and an AO3400A/SS14 relay driver. BOM entries include MPN, rating, package, role, and sourcing warning.

The KiCad board is an un-routed review placement. The legacy schematic must be imported and saved by KiCad 10; custom pins and footprints require official-datasheet review. ERC/DRC say NOT RUN. STEP shapes named envelope are project-authored dimensional clearance shapes, not vendor models. The FreeCAD macro and generated STEP/STL enclosure share a 100 x 70 mm board envelope, but FreeCAD execution and component-accurate board export are not claimed.

## 13. Testing strategy and retained evidence

[[VERIFICATION]]

Testing concentrates on integrity and failure boundaries: contract validation, timestamp consistency, duplicate/collision behavior, alarm hysteresis, authentication, authorization, WebSocket credentials, commands, Modbus bytes, feature leakage, model reproducibility, artifact tamper detection, score direction, fallback, and hardware provenance/release guards.

The host currently passes 47 Python tests with 76.31 percent branch-aware coverage against a 70 percent gate, strict MyPy over 49 product source files, Ruff, hardware static generation checks, dashboard ESLint/TypeScript, and four component tests. Earlier live Compose evidence covers PostgreSQL 18.3, Mosquitto 2.1.2, API, ingestor, simulated gateway, replay, WebSocket, alarms, and relay acknowledgements. A follow-up Compose image and browser run was not executed; no pass is inferred.

## 14. CI, traceability, and quality gates

GitHub Actions workflows define Python lint/type/tests/coverage, dashboard lint/type/tests/build/audit, a clean Compose/API/browser path, report generation/verification, checksum-pinned secret scanning, license policy, and hardware static checks without private credentials or hardware. Third-party actions use full commit SHAs. Hosted jobs are not called passing until the repository is published and they execute. Embedded targets and native CAD remain separate unresolved gates.

Requirements traceability maps each requirement to source, evidence, documentation, and status. The verification report distinguishes PASS, PARTIAL, BLOCKED, NOT RUN, SIMULATED, BENCH-VERIFIED, and FIELD-VALIDATED. A clean CI badge must never be used to imply a physical result.

## 15. Security, privacy, and electrical safety

Local demo credentials are public development values and must be rotated for any other environment. Production needs TLS/WSS, per-device broker credentials or certificates, ACLs, secret management, restricted CORS, backup/retention policy, signed update controls, and a deployment threat review. Telemetry is operational rather than personal, but operators and maintenance notes still require least privilege and retention decisions.

Joblib is a pickle-compatible trusted-artifact format. Only administrator-controlled model roots are acceptable; checksum proves integrity, not authorship. The relay must never switch mains or replace an emergency stop, interlock, personnel protection, or physical isolation. Revision A0-UNVERIFIED must not be fabricated.

## 16. Trade-offs, lessons, limitations, and next steps

The architecture favors explicit contracts and separate processes over a compact monolith; this adds deployment pieces but keeps ingestion, operator API, and model failure independent. Per-device models are less convenient than one global model but make baselines and fallback visible. Bounded queues choose measurable loss over uncontrolled flash growth. An inexpensive two-layer carrier is approachable but demands careful layout and validation.

Credible next steps are to accept/install toolchains, compile both targets with warnings enabled, migrate and route the KiCad design, run ERC/DRC, rebuild FreeCAD outputs, execute all Wokwi scenarios, rerun the changed Compose/dashboard path, assemble a current-limited prototype, retain calibrated bench evidence, and define a controlled field protocol before discussing predictive value.

## 17. Repository map, glossary, references, and appendices

Repository paths are contracts for schemas, services for backend and anomaly processes, web for the dashboard, firmware for ESP32/STM32/shared C, simulator for scenarios and Modbus/Wokwi, hardware for editable review sources, data/demo for versioned synthetic evidence, and docs for ADRs, operations, safety, traceability, and reports.

Glossary: LWT is MQTT Last Will and Testament; QoS is delivery quality of service; RMS is root mean square; CRC is cyclic redundancy check; RTU is Modbus binary serial framing; DE is RS-485 driver enable; ERC/DRC are electrical/design rule checks; SELV/PELV are extra-low-voltage safety classifications.

Primary references and exact verified tool versions are recorded in docs/toolchain-versions.md. Design decisions are in docs/adr. Reproduction details, raw-status boundaries, and command evidence are in docs/verification-report.md, docs/local-development.md, docs/anomaly-detection.md, hardware/README.md, and docs/hardware-in-the-loop.md. The configured GitHub destination is not presented as published until authentication and remote verification succeed.

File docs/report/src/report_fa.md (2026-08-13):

# سکوی هوشمند پایش اینترنت اشیای صنعتی

نویسنده: امین زوروفی
رایانامه: aminn.zoroufi@gmail.com
مخزن پیکربندی شده: https://github.com/aminzoroufi/intelligent-industrial-iot-monitoring-platform
نسخه: ۰.۱.۰
تاریخ: ۲۱ مرداد ۱۴۰۵ برابر با ۱۲ اوت ۲۰۲۶
حق نشر: ۲۰۲۶ امین زوروفی
سطح صحه گذاری: شبیه سازی شده - هیچ ادعای آزمون کارگاهی یا میدانی وجود ندارد
مجوز: منبع در دسترس برای نمونه کار؛ متن سفارشی هنوز نیازمند بررسی حقوقی است

## ۱. چکیده مدیریتی

این سامانه یک نمونه عملی برای پایش پیوسته وضعیت موتور، پمپ یا فن کوچک کارگاهی است. دما، ارتعاش و جریان مستقیم در گره لبه اندازه گیری می شوند؛ داده در قطع شبکه داخل صف محدود نگهداری می شود و سپس با MQTT به پایگاه داده و داشبورد امن می رسد. یک گره Modbus RTU و یک آشکارساز مقایسه ای Isolation Forest نیز مسیر اتصال به تجهیزات قدیمی و تحلیل چندمتغیره را نشان می دهند.

گزارش بر شواهد واقعی مخزن تکیه دارد. با افزودن آزمون های ایستای سخت افزار، ۴۷ آزمون پایتون موفق است و داشبورد نیز آزمون نگارش، نوع سنجی سخت گیرانه و چهار آزمون مؤلفه را می گذراند. اجرای زنده پیشین، دریافت MQTT، بازپخش بدون تکرار، ورود، WebSocket، هشدار و تأیید فرمان رله شبیه سازی شده را پوشش داده است. ساخت هدف های نهفته، ERC و DRC، اجرای پشته تغییر یافته، آزمون فیزیکی و کارایی میدانی هنوز تأیید نشده اند.

## ۲. مسئله نگهداری و دلیل انتخاب پروژه

در یک کارگاه کوچک، بازدید موتور و فن معمولا دوره ای و دستی است. خرابی یاتاقان، اضافه بار، گرفتگی مسیر خنک کاری، اتصال سست یا خرابی حسگر ممکن است میان دو بازدید شکل بگیرد. سامانه کامل SCADA یا نگهداری پیش بینانه برای یک تجهیز کم ارزش می تواند پرهزینه باشد و راهکار فقط ابری نیز در شبکه ناپایدار قابل اتکا نیست.

این مسئله انتخاب شد زیرا زمان بندی نهفته، پروتکل صنعتی، یکپارچگی داده، تجربه اپراتور، الکترونیک و تحلیل صادقانه را در یک محصول منسجم کنار هم قرار می دهد، بی آنکه مشتری یا استقرار واقعی ساخته شود. تجهیز مرجع motor-01 در محل شبیه سازی شده workshop-demo است. هدف، جلب توجه زودتر و مستندتر تعمیرکار است؛ نه تشخیص قطعی یا خاموشی ایمنی خودکار.

## ۳. ذی نفعان، دامنه، ایمنی و معیار موفقیت

کاربران اصلی اپراتور نگهداری، کارشناس کالیبراسیون، مدیر سامانه و مهندس ارزیاب امکان بازسازی هستند. مشاهده وضعیت زنده، تأیید هشدار، ثبت کالیبراسیون و تعمیرات، خروجی محدود، بازپخش آفلاین و مقایسه آشکارساز قطعی و آماری از موارد استفاده اند.

- در دامنه: یک دروازه ESP32، یک گره کوچک STM32 و Modbus، حسگرها، رله نمایشی کم ولتاژ، سرویس های محلی، شبیه سازی و منابع مهندسی ویرایش پذیر.
- بیرون از دامنه: کلیدزنی برق شهر، توقف اضطراری، حفاظت گواهی شده، کنترل خودکار خطرناک، استقرار مشتری، دسترس پذیری بالا و ادعای پیش بینی میدانی.
- موفقیت یعنی قرارداد داده قابل بازتولید، بازپخش idempotent، تغییرات احراز و ممیزی شده، سلامت و خطای آشکار، منطق میزبان آزموده و شکاف های راستی آزمایی قابل مشاهده.

## ۴. معماری و جریان سراسری داده

[[ARCHITECTURE]]

حسگرها از راه I2C، رابط SPI همراه وقفه آماده بودن داده، مسیر اندازه گیری جریان و UART متصل به فرستنده گیرنده RS-485 به ESP32 وصل می شوند. دروازه داده را اعتبارسنجی و تجمیع می کند، شماره ترتیب می دهد، در صف می گذارد و پاکت نسخه دار MQTT را می فرستد. سرویس دریافت، هویت موضوع و JSON Schema را پیش از ثبت تراکنشی دستگاه، تله متری و هشدار آستانه کنترل می کند.

FastAPI رابط REST احراز شده و WebSocket با Origin دقیق فراهم می کند. سازوکار LISTEN و NOTIFY پایگاه PostgreSQL رویداد را میان فرایندها جابه جا می کند. داشبورد Next.js برای REST از واسط هم مبدأ و برای WebSocket مرورگر از کوکی HttpOnly بهره می برد.

## ۵. دروازه ESP32، حسگرها و رفتار بلادرنگ

کد ESP-IDF نسخه ۶.۰.۲ درایور تولیدی را از منطق مشترک C جدا می کند. TMP117 و INA219 روی I2C، حسگر ADXL345 روی SPI و وقفه داده، و MAX3485 روی UART با زمان بندی صریح DE قرار دارند. وظیفه های FreeRTOS نمونه برداری، تجمیع، MQTT، فرمان، سلامت و پایش خطا را جدا می کنند.

منطق میزبان، نسخه و CRC پیکربندی، مهاجرت و مقدار امن، RMS و قله و ضریب تاج، کیفیت نمونه، هیسترزیس، صف محدود با حذف قدیمی ترین رکورد، موضوع و سریال سازی و اتصال مجدد نمایی با jitter را پوشش می دهد. NVS از خانه های مستقل، دفتر رخداد در انتظار و رزرو بازه شماره ترتیب استفاده می کند تا قطع برق ترتیب را پنهان نکند.

رله با وضعیت خاموش آغاز می شود، شناسه و انقضا را بررسی می کند و پس از زمان محدود خودکار خاموش می شود. نگهبان وظیفه و محافظ حلقه راه اندازی دوباره، علت reset را گزارش می کنند. چون ابزار ESP-IDF و زنجیره C قابل استفاده موجود نبود، ساخت هدف ادعا نشده است.

## ۶. گره STM32 و Modbus RTU

طرح STM32F103C8T6 با HAL خانواده STM32CubeF1 از TIM3 برای تحریک نمونه ۱۰ هرتز استفاده می کند. داده ADC در نقشه نسخه دار ۱۸ ثبات قرار می گیرد، USART2 با 115200 8E1 کار می کند و DE گذرگاه RS-485 صریح است. تابع 0x03 ثبات ها را می خواند و نوشتن محدود 0x06 فقط پیکربندی مجاز را با CRC در صفحه پایانی فلش نگه می دارد.

تابع، نشانی، مقدار، CRC، timeout و داده کهنه پاسخ روشن دارند. نگهبان، شمارنده reset و پرچم خطا وضعیت را قابل بررسی می کنند. پنج آزمون پایتون بایت های طلایی، CRC، پاسخ استثنا، کهنگی، timeout و رفت و برگشت شبه پایانه را تأیید می کنند؛ ساخت C و هدف ARM همچنان مسدود است.

## ۷. راه اندازی، ارتباط، صف و سلامت دستگاه

راه اندازی عمدا محلی است: فرمان سریال مقدارهای محدود را می پذیرد، رازها را بازنمی گرداند و بازنشانی کارخانه ای به توالی چندمرحله ای نیاز دارد. اتصال دوباره Wi-Fi و MQTT از backoff نمایی محدود همراه jitter پیروی می کند. موضوع MQTT شامل محل، دستگاه و نوع پیام است؛ تله متری QoS 1 دارد، سلامت retained است و LWT قطع غیرمنتظره را نشان می دهد.

در نبود کارگزار، صف محدود فلش ظرفیت، عمق، تعداد حذف و پرچم بازپخش را ثبت می کند. تنها پس از پر شدن، قدیمی ترین پیام حذف می شود و ترتیب ذخیره در بازپخش حفظ می گردد. نمونه بدون ساعت همگام به جای زمان ساختگی، زمان دستگاه null و uptime دارد. heartbeat توان سیگنال، علت و شمار reset، نسخه، صف، Modbus و خطاهای فعال را نمایش می دهد.

## ۸. داده پشتی، API، احراز هویت و ممیزی

PostgreSQL کاربر، دستگاه، آستانه، تله متری، سلامت، هشدار، کالیبراسیون، تعمیرات، فرمان، ممیزی، خطا و رجیستری مدل را نگه می دارد. یکتایی شناسه پیام و زوج دستگاه و ترتیب، تحویل تکراری را بی اثر و استفاده متعارض از ترتیب را رد می کند. ترتیب و uptime از عدد ۶۴ بیتی استفاده می کنند.

FastAPI بازه زمان و ورودی را محدود می کند، خطای صریح می دهد، آغاز خطرناک سلول CSV را خنثی می سازد و مسیر فایل مدل یا راز را منتشر نمی کند. ورود OAuth2 توکن JWT کوتاه عمر و audience دار می دهد. تغییرات مدیر رویداد ممیزی می سازند. WebSocket مرورگر Origin دقیق و کوکی HttpOnly می خواهد و ابزار خط فرمان توکن را در subprotocol می فرستد، نه در نشانی URL.

## ۹. داشبورد و گردش کار نگهداری

داشبورد واکنش گرا وضعیت ناوگان، سلامت دستگاه، نمودار محدود با گسست و واحد SI، خط آستانه، تاریخچه و تأیید هشدار، کالیبراسیون، تعمیرات، آستانه، CSV، فرمان رله و صفحه حقوقی را فراهم می کند. درخواست های مستقل نخست در Server Component هم زمان اجرا می شوند و کنترل تعاملی در Client Component کوچک می ماند.

صفحه مقایسه آشکارساز، آمادگی مدل را از رجیستری می خواند. منبع threshold، sensor_rule و anomaly جداست و وضعیت آماده نبودن، کهنگی و خطا دیده می شود. نسخه مدل، شمار آموزش و معیارهای شبیه سازی شده نمایش داده می شوند. ساخت تولیدی و آزمون مرورگر ورود و ناوگان پیش از اصلاح نام loopback موفق بود؛ بازسازی لازم پس از اصلاح اجازه اجرا نگرفت و آن مسیر هنوز مسدود است.

## ۱۰. مدل ناهنجاری و تفسیر صادقانه

[[DETECTION_METRICS]]

نسخه ۱ ویژگی ها از پنجره علّی دنباله رو استفاده می کند: سطح و شیب و پراکندگی دما، میانگین و پراکندگی جریان، میانگین RMS ارتعاش، بیشینه قله، ضریب تاج و نسبت ارتعاش به جریان. آموزش فقط بازه سالم انتخاب شده با کیفیت خوب و بدون پرچم خطا را می پذیرد، تقسیم زمانی دارد، seed برابر 20260811 است و طرح، نسخه کتابخانه، بازه، شمار و checksum را ثبت می کند.

امتیاز ذخیره شده منفی score_samples است؛ پس مقدار بزرگ تر ناهنجارتر است. percentile رتبه تجربی میان امتیازهای اعتبارسنجی سالم است و احتمال نیست. دلیل، مقدار مشاهده شده و صدک یک و نود و نه سالم را بیان می کند و علت مکانیکی نمی سازد. نبودن، گیرکردن، نویز، بازه ناممکن، ناسازگاری و نرخ بیش از حد حسگر همچنان قانون قطعی اند.

در داده بذری، F1 مدل 0.7293 و نرخ مثبت کاذب 0.0545 است؛ F1 آستانه همراه قانون حسگر 0.6787 و نرخ مثبت کاذب آن صفر است. این اعداد فقط مقایسه روی fixture مصنوعی اند.

## ۱۱. شبیه سازی و بازتولید دقیق

مولد تله متری سناریوهای عادی، افزایش دما، عدم تعادل ارتعاش، اضافه جریان و حسگر گیرکرده را با seed ثابت می سازد. پروژه های Wokwi مرز درایور ESP32 و STM32 را در بخش های پشتیبانی شده جایگزین می کنند و شبیه ساز PTY بدون گذرگاه برقی Modbus را می آزماید. وفاداری آنالوگ، RF، jitter وقفه، فرسایش فلش، brownout و کیفیت الکتریکی RS-485 شبیه سازی نمی شوند.

- فایل .env.example را به .env کپی کنید و docker compose up --build -d را اجرا کنید.
- سناریوی نام دار را با python -m simulator.telemetry_generator.main normal منتشر کنید.
- آزمون های پایتون، Ruff، MyPy و سپس lint و typecheck و test و build داشبورد را جدا اجرا کنید.
- گزارش آشکارساز را با python -m services.anomaly_worker.main evaluate-demo بازسازی کنید.

## ۱۲. شماتیک، برد، BOM، مدل و محفظه

[[BOARD]]

سخت افزار A0-UNVERIFIED بسته بازبینی است و اجازه ساخت ندارد. طرح ESP32-WROOM-32E، TMP117، INA219 و شنت ۵۰ میلی اهم ۱ وات، ADXL345، MAX3485 با termination اختیاری ۱۲۰ اهم و bias برابر ۶۸۰ اهم، حفاظت SM712، رگولاتور AP2112K و درایور رله AO3400A و SS14 را انتخاب می کند. BOM شماره قطعه سازنده، درجه، پکیج، نقش و هشدار تأمین دارد.

برد KiCad فقط چیدمان مسیربندی نشده است. شماتیک قدیمی باید در KiCad 10 وارد و ذخیره شود و پایه و footprint با دیتاشیت رسمی بررسی گردد. ERC و DRC اجرا نشده اند. فایل STEP با نام envelope فقط حجم مهندسی ساخته پروژه است، نه مدل سازنده. ماکروی FreeCAD و STEP و STL از ابعاد برد ۱۰۰ در ۷۰ میلی متر استفاده می کنند، ولی اجرای FreeCAD و خروجی دقیق قطعات ادعا نمی شود.

## ۱۳. راهبرد آزمون و شواهد نگهداری شده

[[VERIFICATION]]

آزمون بر مرز خطا و یکپارچگی متمرکز است: قرارداد، سازگاری زمان، تکرار و برخورد، هیسترزیس، احراز و مجوز، اعتبار WebSocket، فرمان، بایت Modbus، نشت زمانی ویژگی، بازتولید مدل، دستکاری artifact، جهت امتیاز، fallback و حفاظت انتشار سخت افزار.

میزبان اکنون ۴۷ آزمون پایتون با پوشش شاخه ای ۷۶٫۳۱ درصد در برابر دروازه ۷۰ درصد، MyPy سخت گیرانه روی ۴۹ فایل محصول، Ruff، بررسی ایستای سخت افزار، ESLint و TypeScript و چهار آزمون داشبورد را می گذراند. شاهد زنده پیشین PostgreSQL، Mosquitto، API، ingestor، دروازه شبیه سازی شده، بازپخش، WebSocket، هشدار و تأیید رله را پوشش می دهد. اجرای دوباره تصویر Compose و مرورگر انجام نشده است و نتیجه ای از آن استنباط نمی شود.

## ۱۴. CI، ردیابی و دروازه کیفیت

گردش های GitHub Actions دروازه lint و type و test و coverage پایتون، آزمون و build و audit داشبورد، مسیر پاک Compose و API و مرورگر، بازسازی گزارش، جستجوی راز با checksum ثابت، سیاست مجوز و آزمون ایستای سخت افزار را تعریف می کنند. Action بیرونی با SHA کامل قفل است. تا انتشار مخزن و اجرای میزبان، CI موفق ادعا نمی شود و هدف نهفته و CAD بومی همچنان دروازه جدا و حل نشده اند.

جدول ردیابی هر نیازمندی را به منبع، شاهد، سند و وضعیت پیوند می دهد. گزارش راستی آزمایی میان PASS، PARTIAL، BLOCKED، NOT RUN، SIMULATED، BENCH-VERIFIED و FIELD-VALIDATED فرق می گذارد. سبز شدن CI به معنی نتیجه فیزیکی نیست.

## ۱۵. امنیت، حریم خصوصی و ایمنی برق

اعتبارهای نمونه محلی عمومی اند و در هر محیط دیگر باید تعویض شوند. استقرار واقعی TLS و WSS، اعتبار جدا برای دستگاه، ACL کارگزار، مدیر راز، CORS محدود، نسخه پشتیبان، سیاست نگهداری، کنترل به روزرسانی امضا شده و بازبینی تهدید می خواهد. تله متری شخصی نیست، ولی هویت اپراتور و یادداشت تعمیرات به حداقل دسترسی نیاز دارد.

Joblib قالبی سازگار با pickle و فقط برای artifact مورد اعتماد است. checksum یکپارچگی را می سنجد، نه نویسنده را. رله هرگز نباید برق شهر را کلید بزند یا جای توقف اضطراری، interlock، حفاظت انسان یا جداسازی فیزیکی را بگیرد. نسخه A0-UNVERIFIED نباید ساخته شود.

## ۱۶. بده بستان، آموخته ها، محدودیت و گام بعد

معماری قرارداد صریح و فرایند جدا را به monolith کوچک ترجیح می دهد؛ اجزای استقرار بیشتر می شوند، اما خطای دریافت، API و مدل از هم جدا می ماند. مدل هر دستگاه از مدل سراسری دشوارتر است، ولی baseline و fallback را شفاف می کند. صف محدود، اتلاف قابل اندازه گیری را به رشد بی کنترل فلش ترجیح می دهد. برد دولایه ارزان است، اما طرح و آزمون دقیق می خواهد.

گام معتبر بعدی نصب ابزارها، ساخت هر دو هدف با هشدار سخت، مهاجرت و مسیربندی KiCad، ERC و DRC، بازسازی FreeCAD، اجرای سناریوهای Wokwi، اجرای دوباره Compose و داشبورد تغییر یافته، مونتاژ نمونه با محدودکننده جریان، ثبت شاهد کالیبره کارگاهی و تعریف پروتکل میدانی پیش از هر سخن درباره پیش بینی است.

## ۱۷. نقشه مخزن، واژه نامه، منابع و پیوست

مسیر contracts قراردادها، services سرویس و مدل، web داشبورد، firmware کد ESP32 و STM32 و C مشترک، simulator سناریو و Modbus و Wokwi، hardware منبع بازبینی ویرایش پذیر، data/demo شاهد مصنوعی نسخه دار و docs تصمیم، عملیات، ایمنی، ردیابی و گزارش را نگه می دارد.

واژه نامه: LWT پیام آخر MQTT، QoS کیفیت تحویل، RMS ریشه میانگین مربع، CRC کنترل افزونگی چرخه ای، RTU قاب باینری Modbus، DE فعال ساز فرستنده RS-485، ERC و DRC کنترل قانون الکتریکی و طراحی، و SELV یا PELV رده ولتاژ بسیار پایین ایمن است.

نسخه ابزار و منبع رسمی در docs/toolchain-versions.md و تصمیم ها در docs/adr آمده اند. روش بازتولید و مرز شاهد در docs/verification-report.md، docs/local-development.md، docs/anomaly-detection.md، hardware/README.md و docs/hardware-in-the-loop.md قرار دارد. مقصد GitHub تا پیش از احراز و کنترل remote به عنوان مخزن منتشر شده معرفی نمی شود.

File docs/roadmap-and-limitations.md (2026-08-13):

# Roadmap and known limitations

## Current release boundary

The repository is a software-complete, simulated engineering demonstrator. It
is not a V1 fabrication or field release. The API, ingestion, dashboard source,
detectors, telemetry/Modbus simulators, shared embedded logic, reports, and
review hardware artifacts are implemented. The verification report is the
authority for executed evidence.

Known gaps are deliberately not hidden:

- the ESP32 ESP-IDF target has not been compiled, measured, or run in Wokwi;
- the STM32 ARM target has not been compiled or run in Wokwi;
- the carrier is intentionally un-routed and the stored ERC/DRC reports say
  `NOT RUN`; current Gerber-like files are review artifacts, not build data;
- engineering-envelope STEP shapes are not component-accurate vendor models;
- no physical bench, environmental, EMC, isolation, endurance, or field data
  exists;
- the fixed live browser channel still needs a rebuilt Compose/Playwright run
  and a real screenshot;
- the GitHub workflows are source-validated locally but cannot pass until a
  repository is published and the hosted jobs actually execute;
- exact container tags are selected, but immutable image digests are a future
  supply-chain hardening step;
- the custom source-available license remains marked for legal review.

## Phase 1 — toolchain closure

Run shared C tests on Linux CI, compile ESP-IDF 6.0.2 with a size report, and
compile STM32CubeF1 1.8.6 with the pinned ARM toolchain. Run both Wokwi projects
and retain normal, sensor-fault, reconnect/replay, watchdog, CRC, and timeout
serial evidence. Exit when failures and skips are zero or explicitly waived by
a dated engineering decision.

## Phase 2 — native ECAD/MCAD and bench

Import the review schematic into KiCad 10, replace custom review constructs
with validated library items, complete the power/return/RS-485 layout, inspect
creepage and connector clearances, and pass ERC/DRC without unexplained waivers.
Use official vendor/KiCad models where licenses and part identity are verified,
then export the actual board STEP and regenerate the FreeCAD enclosure. Build
one extra-low-voltage prototype and execute the HIL guide with a directly
accessible actuator-power disconnect.

## Phase 3 — release and measured evaluation

Publish the pre-release, let CI run the clean Compose and desktop/mobile browser
flow, capture a source-traceable dashboard screenshot, and pin deployment image
digests. Collect a reviewed healthy baseline and named controlled faults from
the bench; report confidence intervals and false alarms without promoting the
result to field validation. Field validation requires a separate protocol,
site authorization, qualified safety review, and enough representative
operating time to support the claim.

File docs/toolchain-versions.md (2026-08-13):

# Toolchain versions

Version selection was checked on 2026-08-11 against the linked primary project
sources. Patch versions are locked in their owning manifests or container
references; this table records the architecture baseline.

| Tool | Selected line | Verification source | Rationale |
| --- | --- | --- | --- |
| Python | 3.14.6 | https://www.python.org/downloads/release/python-3146/ | Current stable maintenance release |
| FastAPI | 0.141.1 | https://pypi.org/project/fastapi/ | Current non-prerelease package |
| Pydantic | 2.13.4 | https://pypi.org/project/pydantic/ | Current non-prerelease package |
| SQLAlchemy | 2.0.51 | https://pypi.org/project/SQLAlchemy/ | Current stable 2.0 release; 2.1 was beta |
| psycopg | 3.3.4 | https://pypi.org/project/psycopg/ | Current non-prerelease package |
| Paho MQTT | 2.1.0 | https://pypi.org/project/paho-mqtt/ | Maintained MQTT v5-capable release |
| scikit-learn | 1.9.0 | https://pypi.org/project/scikit-learn/ | Current non-prerelease package |
| Node.js | 24.15.0 | https://nodejs.org/en/about/previous-releases | Active LTS container runtime |
| Next.js | 16.2.12 | https://nextjs.org/blog | Active LTS security release; 16.3 is preview |
| React | 19.2.8 | https://www.npmjs.com/package/react | Exact dashboard runtime lock |
| Mosquitto | 2.1.2 (`2.1.2-alpine` image) | https://mosquitto.org/blog/ and https://hub.docker.com/_/eclipse-mosquitto/tags | Current bug-fix release and exact published official image tag |
| PostgreSQL | 18.3 (`18.3-bookworm` image) | https://www.postgresql.org/developer/roadmap/ and https://hub.docker.com/_/postgres | Current supported major/minor before the scheduled 2026-08-13 update |
| ESP-IDF | 6.0.2 | https://docs.espressif.com/projects/esp-idf/en/stable/esp32/get-started/index.html | Current stable documentation and exact component constraint; target build not yet executed |
| STM32CubeF1 | 1.8.6 | https://www.st.com/en/embedded-software/stm32cubef1.html | Current STM32F1 package selected for an external exact-tag checkout; target build not yet executed |
| KiCad | 10.0.4 | https://www.kicad.org/blog/ | Current stable bug-fix release |
| ReportLab | 4.4.9 | https://pypi.org/project/reportlab/ | Exact reproducible PDF generator lock |
| pip-audit | 2.10.1 | https://pypi.org/project/pip-audit/ | Exact CI vulnerability-audit tool |
| Gitleaks | 8.30.1 | https://github.com/gitleaks/gitleaks/releases/tag/v8.30.1 | Exact binary and Linux x64 SHA-256 pinned in CI |
| `actions/checkout` | 7.0.1 | https://github.com/actions/checkout/releases/tag/v7.0.1 | Full release commit pinned in workflows |
| `actions/setup-python` | 7.0.0 | https://github.com/actions/setup-python/releases/tag/v7.0.0 | Full immutable release commit pinned in workflows |
| `actions/setup-node` | 7.0.0 | https://github.com/actions/setup-node/releases/tag/v7.0.0 | Full immutable release commit pinned in workflows |
| `actions/upload-artifact` | 7.0.1 | https://github.com/actions/upload-artifact/releases/tag/v7.0.1 | Full release commit pinned in workflows |

All Python runtime and JavaScript transitive versions and license expressions
are recorded in `docs/dependency-license-inventory.csv`. Container tags are
exact, but their immutable registry digests are not yet locked and remain a
documented supply-chain improvement. A version is not called verified here
solely because it is familiar; each entry has a dated primary source. GitHub
Action and security-tool selections were rechecked on 2026-08-12.

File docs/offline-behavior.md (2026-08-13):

# Offline monitoring and ordered replay

The ESP32 continues sensor sampling, aggregation, deterministic threshold
tracking, watchdog service, and health/fault accounting while MQTT or Wi-Fi is
unavailable. New telemetry enters a bounded NVS-backed ring. The default is 32
one-second records; the allowed capacity is 1–32 records so storage consumption
and recovery time remain bounded.

When full, the queue drops exactly one oldest record before adding the newest.
It increments a persistent dropped-message counter and raises
`OFFLINE_QUEUE_DROP`. This favors recent condition evidence while making loss
observable. It is not lossless historian storage.

After reconnect, the communication task publishes the oldest queued record at
QoS 1 before newer records. It preserves message UUID, sequence, measurement,
quality, fault, device time, and uptime fields, changing only `replayed` to
`true`. A record is removed after the MQTT library accepts it for delivery. A
reset at that boundary can republish it, so backend UUID uniqueness is the final
idempotency control. Per-device sequence numbers order records; no ordering is
assumed across devices or MQTT topics.

The retry delay starts at one second, doubles to a 30-second cap, and adds up to
20 percent bounded jitter. A network disconnect forces the low-voltage relay
OFF. Flash-wear lifetime, RF reconnection timing, and behavior during real
brownouts require bench verification; Wokwi cannot establish them.

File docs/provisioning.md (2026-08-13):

# Provisioning and configuration recovery

Provisioning is deliberately local and time-limited. An unprovisioned ESP32
keeps the demo relay OFF and accepts serial input for 120 seconds. Connect a
3.3 V USB/UART interface with the board powered from its documented low-voltage
supply, open the configured console baud rate, and enter one setting per line:

```text
SHOW
SET site_id=workshop-demo
SET device_id=motor-01
SET wifi_ssid=<local SSID>
SET wifi_password=<local password>
SET mqtt_host=<private broker address>
SET mqtt_port=1883
SET sample_interval_ms=100
SET telemetry_interval_ms=1000
COMMIT
```

Plain MQTT port 1883 is only for the isolated local demonstration. A deployment
should use TLS, broker authentication or client certificates, per-device ACLs,
encrypted NVS/flash, and a protected commissioning channel. Do not paste a
production credential into logs, screenshots, issue reports, or this
repository.

`SHOW` masks the Wi-Fi password. `COMMIT` succeeds only after identifier,
endpoint, timing, queue, threshold, hysteresis, schema, and CRC validation. A
timeout or `ABORT` changes nothing. The operator reboots to re-enter the window.

## Factory reset

Remove power from the demonstration actuator first. Hold the provision/reset
button continuously while resetting the ESP32. The device announces that reset
is armed; releasing the button cancels it. Only a continuous ten-second hold
erases the project's NVS namespace and restarts in the unprovisioned safe state.
The action erases Wi-Fi/MQTT settings, sequence reservation metadata, queue
records, and reset counters. It does not erase unrelated devices or host data.

## Corruption and migration

The version-1 configuration contains a schema version and CRC-32. A valid
version-0 public settings structure has an explicit migration path. Unknown,
truncated, or checksum-invalid data is not partially trusted: conservative
defaults load, `CONFIG_FALLBACK` is reported, networking requires provisioning,
and the relay stays OFF. There is no automatic remote factory reset command.

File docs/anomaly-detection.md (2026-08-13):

# Anomaly detection and model lifecycle

The anomaly subsystem is a comparison detector, not a safety controller and not
a prediction of remaining useful life. Deterministic threshold hysteresis,
sensor-quality flags, impossible-range checks, rate checks, missing data, and
stuck/noisy sensor rules remain authoritative whether or not a statistical model
is ready.

## Causal feature schema

Feature schema version 1 uses a trailing 12-sample window, requires at least six
finite samples, and resets across gaps longer than 30 seconds. No future sample
is used.

| Feature | Unit / interpretation |
| --- | --- |
| temperature level | °C at the current sample |
| temperature slope | °C/min from the causal window |
| temperature variation | population standard deviation in °C |
| current mean and variation | A |
| vibration RMS mean | m/s² |
| vibration peak maximum | m/s² |
| crest-factor mean | dimensionless ratio |
| vibration/current ratio | m/s²/A, denominator bounded away from zero |

Training windows accept only complete `quality=good` telemetry with no fault
flags. A window containing one rejected sample is excluded in full. This is an
explicit healthy-baseline policy, not an assumption that all historical data is
healthy.

## Training and registry

Select and review a healthy window using UTC `received_at` timestamps, then run:

```sh
docker compose exec anomaly-worker python -m services.anomaly_worker.main train \
  --device-id motor-01 \
  --start 2026-08-11T08:00:00Z \
  --end 2026-08-11T09:00:00Z
```

The default gate requires 200 feature rows. Data is split chronologically into
training and validation portions; the estimator uses 200 trees, contamination
`0.02`, one worker, and fixed seed `20260811`. A deterministic model version is
derived from the device, selected interval, schema, contamination, and seed.

The artifact is stored under `IIOT_MODEL_ROOT` and registered in PostgreSQL with
its feature schema, interval, row counts, library version, SHA-256 checksum, and
last-scored time. The API exposes registry metadata at
`GET /api/v1/devices/{device_id}/anomaly-model` but never exposes the internal
artifact path.

Model files are serialized with Joblib. That format can execute code while
loading, so the model root is an administrator-controlled trust boundary: never
place uploaded or untrusted model files there. The worker resolves registry
paths beneath the configured root, verifies the adjacent artifact checksum,
cross-checks it against PostgreSQL, and requires exact feature-schema and
scikit-learn versions before loading.

## Scoring, explanations, and fallback

The raw score is `-IsolationForest.score_samples`, so larger values are more
anomalous. The displayed percentile is the empirical rank against healthy
validation scores. It is not a probability or calibrated confidence.

An explanation identifies up to two features outside the healthy training
window's 1st/99th percentiles, with value and unit. If the estimator detects an
unusual multivariate combination without a univariate tail, the reason says so
without inventing a mechanical diagnosis.

The model states are:

- `model_not_ready`: no registered model; rules continue and a rate-limited
  diagnostic is persisted;
- `ready`: checksum/schema/version checks passed and scoring is enabled;
- `stale`: the artifact exceeds `IIOT_MODEL_STALE_AFTER_DAYS`; retraining is
  required and statistical scoring stops;
- `error`: path, metadata, checksum, or compatibility validation failed; rules
  continue and the failure is visible.

Statistical alarms use source `anomaly`. Independent sensor-rule alarms use
source `sensor_rule`. Threshold alarms keep source `threshold`, so operators can
distinguish all three.

## Reproducible synthetic evaluation

Regenerate the versioned report with:

```sh
.venv/bin/python -m services.anomaly_worker.main evaluate-demo
```

The checked-in evidence is
[`data/demo/anomaly-evaluation.v1.json`](../data/demo/anomaly-evaluation.v1.json).
It contains confusion counts, precision, recall, F1, false-positive rate, and
first detection delay for deterministic normal, temperature, vibration,
current, and stuck-sensor fixtures. The current synthetic Isolation Forest
result is F1 `0.7293` with false-positive rate `0.0545`; the deterministic
threshold-plus-sensor result is F1 `0.6787` with false-positive rate `0.0`.

These numbers compare two algorithms on a seeded fixture. They are not bench or
field performance, do not establish a maintenance interval, and must not be
generalized to real equipment without a separately documented validation
protocol.

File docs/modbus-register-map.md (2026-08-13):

# STM32 Modbus RTU register map

Protocol version 1 uses slave address 1 by default, 115200 baud, 8E1, and
standard Modbus CRC-16 (polynomial representation `0xA001`, low CRC byte first).
Function `0x03` reads holding registers; `0x06` writes only the explicitly
writable configuration registers. Multi-register writes and broadcast writes
are not supported.

| Address | Name | Access | Encoding / unit |
| ---: | --- | --- | --- |
| 0 | map version | R | `0x0100` = v1.0 |
| 1 | product identity | R | `0x4949` (`II`) |
| 2 | node address | R/W | 1–247; takes effect after echoed response |
| 3 | firmware version | R | `0x0001` = 0.1 |
| 4 | sensor status | R | 0 good, 1 stale, 2 out of range, 3 ADC error |
| 5 | fault flags | R | bit 0 config fallback, bit 1 ADC range, bit 2 stale, bit 3 UART |
| 6 | fixture temperature | R | signed 0.01 °C |
| 7 | ADC raw | R | 0–4095 counts |
| 8–9 | uptime | R | unsigned 32-bit milliseconds, high word first |
| 10–11 | reset count | R | unsigned 32-bit, high word first |
| 12 | CRC error count | R | low 16 bits |
| 13 | exception count | R | low 16 bits |
| 14–15 | config generation | R | unsigned 32-bit, high word first |
| 16 | calibration offset | R/W | signed 0.01 °C, −5000 to +5000 |
| 17 | calibration gain | R/W | unsigned Q1.15, 16384–65535 |

Reads must request 1–18 registers wholly inside the map. Illegal function,
address, and value exceptions use codes `0x01`, `0x02`, and `0x03`; a flash
persistence failure uses `0x04`. A bad CRC, wrong slave address, incomplete
frame, or timeout receives no RTU response.

## Golden frames

Read registers 0–7 from node 1:

```text
request:  01 03 00 00 00 08 44 0C
response: 01 03 10 01 00 49 49 00 01 00 01 00 00 00 00 10 9A 08 00 A4 0A
```

The response fixture represents 42.50 °C, ADC count 2048, good status, and no
fault flags. Both the C host suite and the executed Python pseudo-terminal suite
assert the exact bytes. Only the Python suite has run in the current environment.

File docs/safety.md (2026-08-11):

# Electrical and operational safety boundary

The reference setup is extra-low-voltage DC only. The relay output is a demo
actuator and is not a safety interlock.

- Never connect the PCB, relay contacts, or measurement front end directly to
  mains voltage.
- Use a current-limited, isolated bench supply appropriate to the selected DC
  motor and board ratings.
- Place a clearly labeled, directly accessible switch in series with actuator
  power so the operator can remove energy without software.
- Power down before altering wiring. Verify polarity and current-shunt ratings.
- Keep rotating parts guarded and secure the motor to a stable fixture.
- Treat temperature and vibration fault injection as controlled demonstrations;
  do not intentionally damage equipment.
- Relay firmware boots OFF, commands expire quickly, and loss of communication
  never energizes the output.

Any move beyond the documented bench requires an electrical, mechanical,
cybersecurity, and functional-safety assessment by qualified people.

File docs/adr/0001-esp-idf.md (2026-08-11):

# ADR 0001: ESP-IDF for the edge gateway

Status: accepted — 2026-08-11

ESP-IDF is selected for the ESP32 gateway because it exposes FreeRTOS tasks,
hardware timers, interrupts, NVS, watchdogs, networking, and build-time target
configuration without concentrating the system in an Arduino loop. Sensor,
queue, threshold, and serialization logic will remain behind C interfaces so it
can run in host tests. The cost is greater setup complexity and target-specific
build tooling, which is justified by the real-time and fault-handling scope.

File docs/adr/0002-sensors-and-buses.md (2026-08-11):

# ADR 0002: Sensor and interface selection

Status: accepted — 2026-08-11

The gateway uses a TMP117 temperature sensor and INA219 DC current monitor over
I2C, an ADXL345 accelerometer over SPI with a data-ready interrupt, UART with a
MAX3485-class transceiver for RS-485, and GPIO for the low-voltage relay and
status signals. These parts provide explicit digital interfaces, realistic
register-level production drivers, and a credible low-voltage retrofit demo.
Simulation adapters may replace the electrical device only at compile time and
must preserve units, range, status, and deterministic fault controls.

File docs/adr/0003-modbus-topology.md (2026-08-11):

# ADR 0003: Focused STM32 Modbus RTU sensor node

Status: accepted — 2026-08-11

The ESP32 is the single Modbus RTU master and one STM32F103C8T6-class node is a
slave on a half-duplex 3.3 V RS-485 link. This demonstrates legacy industrial
interoperability without duplicating the gateway. Function codes 0x03 and 0x06
cover versioned measurement reads and constrained configuration writes. The
node validates CRC, address, register range, and timing and returns standard
exception responses.

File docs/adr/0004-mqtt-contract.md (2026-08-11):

# ADR 0004: Versioned MQTT topics and QoS

Status: accepted — 2026-08-11

Topics are rooted at `iiot/v1/{site_id}/{device_id}`. Telemetry, events,
commands, and acknowledgements use QoS 1 so duplicates are expected and removed
by `message_id`. Health uses QoS 1 and may be retained; availability uses a
retained QoS 1 last-will state. Command payloads include an ID and short expiry.
No ordering is assumed across topics, while per-device sequence numbers expose
gaps and replay order within telemetry.

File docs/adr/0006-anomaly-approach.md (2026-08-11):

# ADR 0006: Isolation Forest as a comparison detector

Status: accepted — 2026-08-11

Deterministic sensor-quality rules and threshold hysteresis remain authoritative
for impossible values and configured bounds. A per-device Isolation Forest
provides a modest comparison using rolling temperature, current, vibration, and
crest-factor features. It is reproducible, handles multivariate outliers, and
does not require invented fault labels. Its score is not a probability; the UI
will show raw score, healthy-baseline percentile, evidence-based reasons, model
metadata, and fallback state.

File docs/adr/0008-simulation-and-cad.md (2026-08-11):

# ADR 0008: Deterministic simulation and editable CAD

Status: accepted — 2026-08-11

Host fixtures and Wokwi provide repeatable fault scenarios while production
drivers retain actual register behavior. KiCad 10 is the editable ECAD source
and FreeCAD is the editable enclosure source. Generated artifacts are retained
only when reproducible from those sources. Every 3D model requires provenance;
an unavailable vendor model is represented only by a clearly labeled,
datasheet-sized engineering envelope. Simulation cannot validate analog
fidelity, RF, flash wear, interrupt jitter, or RS-485 electrical margins.

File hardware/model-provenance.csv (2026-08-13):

file | applies_to | kind | source | source_url | license | retrieval_date | sha256
hardware/3d-models/ESP32-WROOM-32E-envelope.step | U1 | project-authored engineering envelope | Espressif ESP32-WROOM-32E datasheet mechanical drawing | https://www.espressif.com/sites/default/files/documentation/esp32-wroom-32e_esp32-wroom-32ue_datasheet_en.pdf | Project-authored dimensional envelope; not a manufacturer 3D model | 2026-08-11 | 8dfe89b64b9a9bf211ac3bcaa9603d4f150bf74e338393edfc726469232ce121
hardware/3d-models/G5V-1-envelope.step | K1 | project-authored engineering envelope | Omron G5V-1 datasheet mechanical drawing | https://components.omron.com/us-en/datasheet_pdf/J044-E1.pdf | Project-authored dimensional envelope; not a manufacturer 3D model | 2026-08-11 | 8dcb7da90c5e471939062638f15b5547c81d13b8951bad45b5528ef4da03992c

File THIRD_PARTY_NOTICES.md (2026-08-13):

# Third-Party Notices

Third-party packages and container images remain under their own licenses. The
committed `docs/dependency-license-inventory.csv` records all 602 exact Python
runtime and JavaScript lockfile rows, license expressions, scope, and review
disposition. `requirements/python-license-policy.csv` is the reviewed Python
policy input; JavaScript license metadata comes from `web/package-lock.json`.

Core technologies selected at the architecture baseline include ESP-IDF
(Apache-2.0), STM32Cube components (their applicable ST terms), Mosquitto
(EPL-2.0 or EDL-1.0), PostgreSQL (PostgreSQL License), Python (PSF-2.0),
FastAPI (MIT), SQLAlchemy (MIT), Pydantic (MIT), scikit-learn (BSD-3-Clause),
Next.js (MIT), and React (MIT). This summary is informational; exact locked
versions and transitive licenses take precedence.

No third-party binary CAD model is committed. The STEP files named `-envelope`
are project-authored dimensional shapes and their provenance is recorded in
`hardware/model-provenance.csv`.

`docs/report/fonts/NotoSansArabic-Regular.ttf` and
`NotoSansArabic-Bold.ttf` are from the Noto Arabic project, copyright 2022 The
Noto Project Authors, and are distributed under the SIL Open Font License 1.1.
The required copyright and complete license are preserved in
`docs/report/fonts/OFL.txt`. The fonts are embedded into the Persian PDF.

`web/app/fonts/geist-latin.woff2` and `geist-mono-latin.woff2` are unmodified
Geist subsets bundled by the exact locked Next.js 16.2.12 package. Geist is
copyright 2024 The Geist Project Authors and distributed under the SIL Open
Font License 1.1. The required copyright, complete license, source package,
retrieval date, and SHA-256 checksums are preserved in `web/app/fonts/OFL.txt`
and `web/app/fonts/provenance.csv`. They are self-hosted so the dashboard build
does not fetch fonts from a third-party service.

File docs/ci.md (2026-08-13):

# Continuous integration and dependency policy

The CI workflow has four independent gates: Python/contracts/docs/hardware,
dashboard, shared firmware host tests, and the full Compose/browser path. The
security workflow audits both lock files, validates the committed license
inventory, and scans complete Git history with a checksum-pinned Gitleaks
binary. Neither workflow needs private credentials or physical hardware.

Every `uses:` reference is pinned to a full Git commit. The selected releases
were checked against their official GitHub release pages on 2026-08-12:

- `actions/checkout` 7.0.1;
- `actions/setup-python` 7.0.0;
- `actions/setup-node` 7.0.0;
- `actions/upload-artifact` 7.0.1.

Dependabot proposes action updates monthly. A maintainer must read the upstream
release notes, review permission/runtime changes, replace the full SHA and
version comment together, and let all gates pass. Floating major tags are not
accepted.

Python dependency changes require an exact pin in `requirements/runtime.lock`
or `requirements/ci.lock` and a reviewed row in
`requirements/python-license-policy.csv`. The CI lock includes the runtime lock
and fully pins its additional development/documentation graph. JavaScript
changes must be made through `package-lock.json`. Refresh the public inventory
with:

```bash
.venv/bin/python scripts/check_dependency_licenses.py --write
```

The policy rejects absent/unknown licenses and strong-copyleft expressions that
have not received an explicit licensing decision. `reviewed` rows are not legal
advice; they record the engineering distribution decision and preservation
obligations. The project license does not replace any dependency license.

CI compiles only the hardware-independent C core. ESP-IDF, STM32Cube/ARM, KiCad
ERC/DRC, FreeCAD execution, bench tests, and field tests remain separate named
gates and must never be inferred from a green hosted workflow.

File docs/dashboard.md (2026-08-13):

# Operator dashboard

The Next.js dashboard is a responsive operator surface for the simulated
condition-monitoring stack. It is served at `http://localhost:3000` by the
Compose `web` service and uses UTC consistently in displayed timestamps.

## Workflows

- fleet overview with online, degraded, and offline status text plus color;
- device detail with retained health, current measurements, bounded live and
  historical charts, explicit gaps, SI units, and threshold overlays;
- active and historical alarms with acknowledgement state;
- audited threshold, calibration, and maintenance changes;
- short-lived low-voltage demonstration relay commands with separate accepted,
  completed, rejected, and timed-out states;
- bounded CSV export;
- deterministic-threshold versus anomaly-model comparison driven by the model
  registry, with explicit not-ready, ready, stale, and error states plus the
  versioned synthetic metric/scenario report;
- About/legal content with authorship, source license, verification level, and
  safety boundary.

## Authentication boundary

The browser sends credentials only to the dashboard's same-origin login route.
The server-side route exchanges them with FastAPI and stores the resulting JWT
in an HttpOnly, SameSite=Strict cookie. Dashboard REST requests use an explicit
allow-listing backend-for-frontend; browser code does not read or persist the
token. Non-GET proxy requests reject a mismatched Origin when one is present.

Live updates connect directly to FastAPI because a WebSocket upgrade cannot be
proxied through a Next.js route handler. FastAPI requires an exact allowed
browser Origin and authenticates the upgrade from the same host-only HttpOnly
cookie. For local access, the client normalizes `localhost`, `127.0.0.1`, and
`::1` to the hostname of the dashboard page so the cookie scope stays aligned.
Production must use HTTPS/WSS, set `IIOT_COOKIE_SECURE=true`, and replace the
development origins and secrets.

## Rendering and data limits

Initial page reads happen in Server Components and independent requests run in
parallel. Interactive controls are isolated in Client Components. The live
chart retains at most 240 points in browser memory, creates discontinuous SVG
paths for missing samples, labels axes and units, and shows warning/critical
thresholds. Anomaly markers appear only for persisted scored rows; a model
score is never presented as a probability. The comparison route separately
shows threshold alarms, persisted model readiness, recently returned scored
rows, confusion-derived synthetic metrics, and detection delay.

## Verification boundary

ESLint, strict TypeScript compilation, four Vitest component tests, and the
Next.js production build pass. The build now self-hosts checksum-tracked Geist
subsets under SIL OFL 1.1 and succeeds without a Google Fonts request. An
earlier npm audit reported zero vulnerabilities; the latest local rerun could
not reach the registry, so CI must produce the current audit evidence. A prior
browser smoke passed sign-in, fleet rendering, console inspection, and desktop
overflow inspection. The required container rebuild and browser rerun after
the loopback normalization fix were not executed, so the cookie-authenticated
live path is recorded as blocked until it actually runs.

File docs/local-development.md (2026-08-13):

# Local software development

## Prerequisites

- Docker Engine with Compose v2;
- Python 3.12 through 3.14 for host tools;
- a virtual environment populated with `pip install -r requirements/ci.lock`;
- Node.js 24 with `npm ci --prefix web` when running dashboard checks on the
  host.

## Start the backend vertical slice

```sh
cp .env.example .env
make demo
make demo-status
```

If the host's `make` executable is unavailable, the equivalent start command is
`docker compose up --build -d` after creating `.env`; inspect it with
`docker compose ps`.

The seven-service slice starts PostgreSQL, Mosquitto, the API, the MQTT ingestor,
the anomaly worker, a clearly simulated gateway, and the dashboard. Open the dashboard at
`http://localhost:3000`; the API is served on `http://localhost:8000`, OpenAPI
on `/docs`, Mosquitto on localhost port 1883, and PostgreSQL on localhost port
5432. These published ports are for local development only.

The seeded credentials are `demo-admin` and the password shown explicitly in
`.env.example`. They are intentionally public development values, are never a
production recommendation, and must be changed outside the local demo.

## Publish synthetic telemetry

```sh
make scenario-normal
make scenario-temperature
make scenario-vibration
make scenario-current
make scenario-stuck
```

Every line emitted by the generator includes `"synthetic": true`. Reusing the
same scenario session and sequence range intentionally exercises idempotency.

## Exercise authenticated operations

Use the interactive OpenAPI page to obtain a token, inspect fleet state,
acknowledge alarms, record calibration or maintenance, update thresholds, and
issue the demo relay command. The simulated gateway publishes retained health,
starts with its relay state OFF, rejects expired or mismatched commands, and
returns command acknowledgements through MQTT.

The dashboard signs in through its same-origin backend-for-frontend and keeps
the access token in an HttpOnly, SameSite=Strict cookie. Browser JavaScript
cannot read the token. Its direct WebSocket connection is accepted only when
the request Origin exactly matches `IIOT_CORS_ORIGINS`; the API authenticates
the handshake from the HttpOnly cookie. Command-line clients without a browser
Origin can instead offer `bearer` and the access token as WebSocket
subprotocols. Tokens must never be placed in the WebSocket URL because request
URLs are commonly logged. See `docs/operations-workflows.md` for both flows.

## Train and inspect the anomaly comparison

First publish enough normal samples for the default 200-feature-row gate and
review the interval before declaring it healthy:

```sh
.venv/bin/python -m simulator.telemetry_generator.main normal \
  --count 260 --sequence-start 10000 --session-id anomaly-baseline
docker compose exec postgres psql -U iiot_demo -d iiot_demo -c \
  "select min(received_at), max(received_at), count(*) from telemetry where device_id='motor-01';"
make anomaly-train START=2026-08-11T08:00:00Z END=2026-08-11T09:00:00Z
```

Replace the example timestamps with the reviewed query result. The continuously
running worker will score eligible backlog and new rows. The detector-comparison
dashboard shows `MODEL NOT READY`, `READY`, `STALE`, or `ERROR` from the registry
rather than inferring readiness from UI state. See `docs/anomaly-detection.md`.

The reproducible report does not need database credentials:

```sh
.venv/bin/python -m services.anomaly_worker.main evaluate-demo
```

## Quality gate and bounded cleanup

```sh
make check
make clean-demo
```

The exact quality commands behind `make check` are listed in
`docs/verification-report.md` and can be run directly when a host toolchain
prevents Make from starting.

`make clean-demo` removes only containers and the network in the named
`iiot-monitoring-demo` Compose project. `make reset-demo` additionally removes
only that project's PostgreSQL, Mosquitto, and anomaly-model named volumes.

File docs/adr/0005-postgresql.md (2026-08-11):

# ADR 0005: PostgreSQL persistence

Status: accepted — 2026-08-11

PostgreSQL is selected for transactional device and maintenance workflows,
unique constraints for ingestion idempotency, time-range indexes, JSON metadata
where schemas evolve, and repeatable Alembic migrations. SQLite is restricted
to fast unit tests because concurrency, timestamp, and constraint behavior can
differ. Integration and migration evidence must use PostgreSQL.

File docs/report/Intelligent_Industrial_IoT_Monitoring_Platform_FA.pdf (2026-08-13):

# سکوی هوشمند پایش اینترنت اشیای صنعتی

## گزارش مهندسی نمونه کار

نویسنده: امین زوروفی
: aminn.zoroufi@gmail.com | رایانامه
: https://github.com/aminzoroufi/intelligent-industrial-iot-monitoring-platformشده | پیکربندی | مخزن
نسخه۰.۱.۰ :
تاریخ۲۱ : مرداد ۱۴۰۵ برابر با ۱۲ اوت ۲۰۲۶ حق نشر۲۰۲۶ : امین زوروفی
سطح صحه گذاری: شبیه سازی شده - هیچ ادعای آزمون کارگاهی یا میدانی وجود ندارد مجوز: منبع در دسترس برای نمونه کار؛ متن سفارشی هنوز نیازمند بررسی حقوقی است

فقط نمایش کم ولتاژ؛ فاقد گواهی ایمنی، کارگاهی یا میدانی

صفحه 1 شبیه سازی شده - فاقد اعتبار میدانی

سکوی هوشمند پایش اینترنت اشیای صنعتی

# ۱. چکیده مدیریتی

این سامانه یک نمونه عملی برای پایش پیوسته وضعیت موتور، پمپ یا فن کوچک کارگاهی است. دما، ارتعاش و جریان مستقیم در گره لبه اندازه گیری می شوند؛ داده در قطع شبکه داخل صف محدود نگهداری می شود و سپس با MQTT به پایگاه داده و داشبورد امن می رسد. یک گره RTU Modbus و یک آشکارساز مقایسه ای Forest Isolation نیز مسیر اتصال به تجهیزات قدیمی و تحلیل چندمتغیره را نشان می دهند. گزارش بر شواهد واقعی مخزن تکیه دارد. با افزودن آزمون های ایستای سخت افزار، ۴۷ آزمون پایتون موفق است و داشبورد نیز آزمون نگارش، نوع سنجی سخت گیرانه و چهار آزمون مؤلفه را می گذراند. اجرای زنده پیشین، دریافت MQTT، بازپخش بدون تکرار، ورود، WebSocket، هشدار و تأیید فرمان رله شبیه سازی شده را پوشش داده است. ساخت هدف های نهفته، ERC و DRC، اجرای پشته تغییر یافته، آزمون فیزیکی و کارایی میدانی هنوز تأیید نشده اند.

صفحه 2 شبیه سازی شده - فاقد اعتبار میدانی

# ۲. مسئله نگهداری و دلیل انتخاب پروژه

در یک کارگاه کوچک، بازدید موتور و فن معمولا دوره ای و دستی است. خرابی یاتاقان، اضافه بار، گرفتگی مسیر خنک کاری، اتصال سست یا خرابی حسگر ممکن است میان دو بازدید شکل بگیرد. سامانه کامل SCADA یا نگهداری پیش بینانه برای یک تجهیز کم ارزش می تواند پرهزینه باشد و راهکار فقط ابری نیز در شبکه ناپایدار قابل اتکا نیست. این مسئله انتخاب شد زیرا زمان بندی نهفته، پروتکل صنعتی، یکپارچگی داده، تجربه اپراتور، الکترونیک و تحلیل صادقانه را در یک محصول منسجم کنار هم قرار می دهد، بی آنکه مشتری یا استقرار واقعی ساخته شود. تجهیز مرجع -01motor در محل شبیه سازی شده demo-workshop است. هدف، جلب توجه زودتر و مستندتر تعمیرکار است؛ نه تشخیص قطعی یا خاموشی ایمنی خودکار.

صفحه 3 شبیه سازی شده - فاقد اعتبار میدانی

# ۳. ذی نفعان، دامنه، ایمنی و معیار موفقیت

کاربران اصلی اپراتور نگهداری، کارشناس کالیبراسیون، مدیر سامانه و مهندس ارزیاب امکان بازسازی هستند. مشاهده وضعیت زنده، تأیید هشدار، ثبت کالیبراسیون و تعمیرات، خروجی محدود، بازپخش آفلاین و مقایسه آشکارساز قطعی و آماری از موارد استفاده اند. در دامنه: یک دروازه 32ESP، یک گره کوچک 32STM و Modbus، حسگرها، رله نمایشی کم ولتاژ، سرویس های محلی، شبیه سازی و منابع مهندسی ویرایش پذیر.
بیرون از دامنه: کلیدزنی برق شهر، توقف اضطراری، حفاظت گواهی شده، کنترل خودکار خطرناک، استقرار مشتری، دسترس پذیری بالا و ادعای پیش بینی میدانی.
موفقیت یعنی قرارداد داده قابل بازتولید، بازپخش idempotent، تغییرات احراز و ممیزی شده، سلامت و خطای آشکار، منطق میزبان آزموده و شکاف های راستی آزمایی قابل مشاهده.

صفحه 4 شبیه سازی شده - فاقد اعتبار میدانی

# ۴. معماری و جریان سراسری داده

API و داشبورد دریافت و داده کارگزار MQTT لبه 32ESP حسگرها

Modbus و STM32

WebSocket و UART - MQTT - SQL - REST و I2C و : SPIصریح | مرزهای
شکل ۱. معماری سراسری بر پایه مرزهای پیاده سازی شده مخزن. حسگرها از راه C2I، رابط SPI همراه وقفه آماده بودن داده، مسیر اندازه گیری جریان و UART متصل به فرستنده گیرنده -485RS به 32ESP وصل می شوند. دروازه داده را اعتبارسنجی و تجمیع می کند، شماره ترتیب می دهد، در صف می گذارد و پاکت نسخه دار MQTT را می فرستد. سرویس دریافت، هویت موضوع و Schema JSON را پیش از ثبت تراکنشی دستگاه، تله متری و هشدار آستانه کنترل می کند. FastAPI رابط REST احراز شده و WebSocket با Origin دقیق فراهم می کند. سازوکار LISTEN و NOTIFY پایگاه PostgreSQL رویداد را میان فرایندها جابه جا می کند. داشبورد js.Next برای REST از واسط هم مبدأ و برای WebSocket مرورگر از کوکی HttpOnly بهره می برد.

صفحه 5 شبیه سازی شده - فاقد اعتبار میدانی

# ۵. دروازه 32ESP، حسگرها و رفتار بلادرنگ

کد IDF-ESP نسخه ۶.۰.۲ درایور تولیدی را از منطق مشترک C جدا می کند117TMP . و 219INA روی C2I، حسگر 345ADXL روی SPI و وقفه داده، و 3485MAX روی UART با زمان بندی صریح DE قرار دارند. وظیفه های FreeRTOS نمونه برداری، تجمیع، MQTT، فرمان، سلامت و پایش خطا را جدا می کنند. منطق میزبان، نسخه و CRC پیکربندی، مهاجرت و مقدار امن، RMS و قله و ضریب تاج، کیفیت نمونه، هیسترزیس، صف محدود با حذف قدیمی ترین رکورد، موضوع و سریال سازی و اتصال مجدد نمایی با jitter را پوشش می دهدNVS . از خانه های مستقل، دفتر رخداد در انتظار و رزرو بازه شماره ترتیب استفاده می کند تا قطع برق ترتیب را پنهان نکند. رله با وضعیت خاموش آغاز می شود، شناسه و انقضا را بررسی می کند و پس از زمان محدود خودکار خاموش می شود. نگهبان وظیفه و محافظ حلقه راه اندازی دوباره، علت reset را گزارش می کنند. چون ابزار IDF-ESP و زنجیره C قابل استفاده موجود نبود، ساخت هدف ادعا نشده است.

صفحه 6 شبیه سازی شده - فاقد اعتبار میدانی

Modbus RTU و STM32 گره ۶.

طرح 6T8C103F32STM با HAL خانواده 1CubeF32STM از 3TIM برای تحریک نمونه ۱۰ هرتز استفاده می کند. داده ADC در نقشه نسخه دار ۱۸ ثبات قرار می گیرد، 2USART با 1E8 115200 کار می کند و DE گذرگاه -485RS صریح است. تابع 03x0 ثبات ها را می خواند و نوشتن محدود 06x0 فقط پیکربندی مجاز را با CRC در صفحه پایانی فلش نگه می دارد. تابع، نشانی، مقدار، CRC، timeout و داده کهنه پاسخ روشن دارند. نگهبان، شمارنده reset و پرچم خطا وضعیت را قابل بررسی می کنند. پنج آزمون پایتون بایت های طلایی، CRC، پاسخ استثنا، کهنگی، timeout و رفت و برگشت شبه پایانه را تأیید می کنند؛ ساخت C و هدف ARM همچنان مسدود است.

صفحه 7 شبیه سازی شده - فاقد اعتبار میدانی

# ۷. راه اندازی، ارتباط، صف و سلامت دستگاه

راه اندازی عمدا محلی است: فرمان سریال مقدارهای محدود را می پذیرد، رازها را بازنمی گرداند و بازنشانی کارخانه ای به توالی چندمرحله ای نیاز دارد. اتصال دوباره Fi-Wi و MQTT از backoff نمایی محدود همراه jitter پیروی می کند. موضوع MQTT شامل محل، دستگاه و نوع پیام است؛ تله متری 1 QoS دارد، سلامت retained است و LWT قطع غیرمنتظره را نشان می دهد. در نبود کارگزار، صف محدود فلش ظرفیت، عمق، تعداد حذف و پرچم بازپخش را ثبت می کند. تنها پس از پر شدن، قدیمی ترین پیام حذف می شود و ترتیب ذخیره در بازپخش حفظ می گردد. نمونه بدون ساعت همگام به جای زمان ساختگی، زمان دستگاه null و uptime دارد. heartbeat توان سیگنال، علت و شمار reset، نسخه، صف، Modbus و خطاهای فعال را نمایش می دهد.

صفحه 8 شبیه سازی شده - فاقد اعتبار میدانی

# ۸. داده پشتی، API، احراز هویت و ممیزی

PostgreSQL کاربر، دستگاه، آستانه، تله متری، سلامت، هشدار، کالیبراسیون، تعمیرات، فرمان، ممیزی، خطا و رجیستری مدل را نگه می دارد. یکتایی شناسه پیام و زوج دستگاه و ترتیب، تحویل تکراری را بی اثر و استفاده متعارض از ترتیب را رد می کند. ترتیب و uptime از عدد ۶۴ بیتی استفاده می کنند.
FastAPI بازه زمان و ورودی را محدود می کند، خطای صریح می دهد، آغاز خطرناک سلول CSV را خنثی می سازد و مسیر فایل مدل یا راز را منتشر نمی کند. ورود 2OAuth توکن JWT کوتاه عمر و audience دار می دهد. تغییرات مدیر رویداد ممیزی می سازندWebSocket . مرورگر Origin دقیق و کوکی HttpOnly می خواهد و ابزار خط فرمان توکن را در subprotocol می فرستد، نه در نشانی .URL

صفحه 9 شبیه سازی شده - فاقد اعتبار میدانی

# ۹. داشبورد و گردش کار نگهداری

داشبورد واکنش گرا وضعیت ناوگان، سلامت دستگاه، نمودار محدود با گسست و واحد SI، خط آستانه، تاریخچه و تأیید هشدار، کالیبراسیون، تعمیرات، آستانه، CSV، فرمان رله و صفحه حقوقی را فراهم می کند. درخواست های مستقل نخست در Component Server هم زمان اجرا می شوند و کنترل تعاملی در Component Client کوچک می ماند. صفحه مقایسه آشکارساز، آمادگی مدل را از رجیستری می خواند. منبع threshold، rule_sensor و anomaly جداست و وضعیت آماده نبودن، کهنگی و خطا دیده می شود. نسخه مدل، شمار آموزش و معیارهای شبیه سازی شده نمایش داده می شوند. ساخت تولیدی و آزمون مرورگر ورود و ناوگان پیش از اصلاح نام loopback موفق بود؛ بازسازی لازم پس از اصلاح اجازه اجرا نگرفت و آن مسیر هنوز مسدود است.

صفحه 10 شبیه سازی شده - فاقد اعتبار میدانی

# ۱۰. مدل ناهنجاری و تفسیر صادقانه

قواعد

P 100.0 | R 51.4 | F1 67.9 | FPR 0.0

Isolation Forest

P 97.7 | R 58.2 | F1 72.9 | FPR 5.5

معیار داده مصنوعی - نه احتمال و نه کارایی میدانی

شکل ۲. مقایسه بازتولیدپذیر آشکارسازها در گزارش مصنوعی نسخه دار. نسخه ۱ ویژگی ها از پنجره علّی دنباله رو استفاده می کند: سطح و شیب و پراکندگی دما، میانگین و پراکندگی جریان، میانگین RMS ارتعاش، بیشینه قله، ضریب تاج و نسبت ارتعاش به جریان. آموزش فقط بازه سالم انتخاب شده با کیفیت خوب و بدون پرچم خطا را می پذیرد، تقسیم زمانی دارد، seed برابر 20260811 است و طرح، نسخه کتابخانه، بازه، شمار و checksum را ثبت می کند. امتیاز ذخیره شده منفی samples_score است؛ پس مقدار بزرگ تر ناهنجارتر استpercentile . رتبه تجربی میان امتیازهای اعتبارسنجی سالم است و احتمال نیست. دلیل، مقدار مشاهده شده و صدک یک و نود و نه سالم را بیان می کند و علت مکانیکی نمی سازد. نبودن، گیرکردن، نویز، بازه ناممکن، ناسازگاری و نرخ بیش از حد حسگر همچنان قانون قطعی اند. در داده بذری، 1F مدل 0.7293 و نرخ مثبت کاذب 0.0545 است؛ 1F آستانه همراه قانون حسگر 0.6787 و نرخ مثبت کاذب آن صفر است. این اعداد فقط مقایسه روی fixture مصنوعی اند.

صفحه 11 شبیه سازی شده - فاقد اعتبار میدانی
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

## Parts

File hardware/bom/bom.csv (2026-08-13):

references | quantity | manufacturer | manufacturer_part_number | value | package | rating | role | sourcing_note
C1 | 1 | Panasonic | EEE-FK1A101P | 100uF | SMD_D8 | 100 uF, 10 V | input bulk decoupling | Verify lifecycle, authorized source, stock, and current datasheet before build
C10 | 1 | Murata | GRM188R71C104KA01D | 100nF | 0603 | 100 nF, 16 V, X7R | MAX3485 decoupling | Verify lifecycle, authorized source, stock, and current datasheet before build
C2 | 1 | Murata | GRM21BR61A106KE19L | 10uF | 0805 | 10 uF, 10 V, X5R | regulator input decoupling | Verify lifecycle, authorized source, stock, and current datasheet before build
C3 | 1 | Murata | GRM21BR61A106KE19L | 10uF | 0805 | 10 uF, 10 V, X5R | regulator output decoupling | Verify lifecycle, authorized source, stock, and current datasheet before build
C4 | 1 | Murata | GRM31CR61A226ME15L | 22uF | 1206 | 22 uF, 10 V, X5R | ESP32 local bulk decoupling | Verify lifecycle, authorized source, stock, and current datasheet before build
C5 | 1 | Murata | GRM188R71C104KA01D | 100nF | 0603 | 100 nF, 16 V, X7R | ESP32 high-frequency decoupling | Verify lifecycle, authorized source, stock, and current datasheet before build
C6 | 1 | Murata | GRM188R71C104KA01D | 100nF | 0603 | 100 nF, 16 V, X7R | TMP117 decoupling | Verify lifecycle, authorized source, stock, and current datasheet before build
C7 | 1 | Murata | GRM188R71C104KA01D | 100nF | 0603 | 100 nF, 16 V, X7R | INA219 decoupling | Verify lifecycle, authorized source, stock, and current datasheet before build
C8 | 1 | Murata | GRM188R71C104KA01D | 100nF | 0603 | 100 nF, 16 V, X7R | ADXL345 high-frequency decoupling | Verify lifecycle, authorized source, stock, and current datasheet before build
C9 | 1 | Murata | GRM21BR61A106KE19L | 10uF | 0805 | 10 uF, 10 V, X5R | ADXL345 local bulk decoupling | Verify lifecycle, authorized source, stock, and current datasheet before build
D1 | 1 | onsemi | SS34 | SS34 | SMA | 3 A, 40 V | reverse-polarity series protection | Verify lifecycle, authorized source, stock, and current datasheet before build
D2 | 1 | Littelfuse | SMBJ5.0A | SMBJ5.0A | SMB | 5 V standoff | 5 V transient clamp | Verify lifecycle, authorized source, stock, and current datasheet before build
D3 | 1 | Littelfuse | SM712-02HTG | SM712 | SOT-23 | asymmetric RS-485 TVS | RS-485 transient protection | Verify lifecycle, authorized source, stock, and current datasheet before build
D4 | 1 | onsemi | SS14 | SS14 | SMA | 1 A, 40 V | relay flyback diode | Verify lifecycle, authorized source, stock, and current datasheet before build
F1 | 1 | Bourns | MF-MSMF110-2 | 1.1A PTC | 1812 | 1.1 A hold, 6 V | resettable input overcurrent protection | Verify lifecycle, authorized source, stock, and current datasheet before build
J1 | 1 | Phoenix Contact | 1715721 | 5V INPUT | TerminalBlock_2P_5.08mm | 5 VDC, 1.5 A project limit | SELV/PELV power input | Verify lifecycle, authorized source, stock, and current datasheet before build
J2 | 1 | Phoenix Contact | 1729128 | MODBUS A/B/GND | TerminalBlock_3P_5.08mm | SELV/PELV only | RS-485 field connector | Verify lifecycle, authorized source, stock, and current datasheet before build
J3 | 1 | Phoenix Contact | 1715721 | RELAY COM/NO | TerminalBlock_2P_5.08mm | 30 VDC, 2 A project limit; no mains | extra-low-voltage contact output | Verify lifecycle, authorized source, stock, and current datasheet before build
J4 | 1 | Phoenix Contact | 1715721 | CURRENT PATH | TerminalBlock_2P_5.08mm | 0 to 2 A DC project limit | demonstrator current path | Verify lifecycle, authorized source, stock, and current datasheet before build
J5 | 1 | Harwin | M20-9990546 | UART PROGRAM | PinHeader_1x05_P2.54mm | 3.3 V logic | 3.3 V UART programming header | Verify lifecycle, authorized source, stock, and current datasheet before build
JP1 | 1 | Harwin | M20-9990346 | TERM ENABLE | PinHeader_1x02_P2.54mm | 3 A | termination enable jumper | Verify lifecycle, authorized source, stock, and current datasheet before build
JP2 | 1 | Harwin | M20-9990346 | BIAS A | PinHeader_1x02_P2.54mm | 3 A | fail-safe A bias enable | Verify lifecycle, authorized source, stock, and current datasheet before build
JP3 | 1 | Harwin | M20-9990346 | BIAS B | PinHeader_1x02_P2.54mm | 3 A | fail-safe B bias enable | Verify lifecycle, authorized source, stock, and current datasheet before build
K1 | 1 | Omron Electronics | G5V-1-DC5 | G5V-1-DC5 | Relay_THT_6.5x10mm | project-limited to 30 VDC, 2 A | extra-low-voltage demo relay | Verify lifecycle, authorized source, stock, and current datasheet before build
Q1 | 1 | Alpha & Omega Semiconductor | AO3400A | AO3400A | SOT-23 | 30 V, 5.8 A | low-side relay coil driver | Verify lifecycle, authorized source, stock, and current datasheet before build
R1 | 1 | Yageo | RC0603FR-0710KL | 10k | 0603 | 0.1 W | ESP32 enable pull-up | Verify lifecycle, authorized source, stock, and current datasheet before build
R2 | 1 | Yageo | RC0603FR-0710KL | 10k | 0603 | 0.1 W | boot strap pull-up | Verify lifecycle, authorized source, stock, and current datasheet before build
R3 | 1 | Vishay | WSL2512R0500FEA | 0.05R 1% | 2512 | 0.05 ohm, 1 W | current shunt | Verify lifecycle, authorized source, stock, and current datasheet before build
R4 | 1 | Yageo | RC0805FR-07120RL | 120R | 0805 | 0.125 W | selectable RS-485 termination | Verify lifecycle, authorized source, stock, and current datasheet before build
R5 | 1 | Yageo | RC0603FR-07680RL | 680R | 0603 | 0.1 W | RS-485 A bias resistor | Verify lifecycle, authorized source, stock, and current datasheet before build
R6 | 1 | Yageo | RC0603FR-07680RL | 680R | 0603 | 0.1 W | RS-485 B bias resistor | Verify lifecycle, authorized source, stock, and current datasheet before build
R7 | 1 | Yageo | RC0603FR-07100RL | 100R | 0603 | 0.1 W | MOSFET gate resistor | Verify lifecycle, authorized source, stock, and current datasheet before build
R8 | 1 | Yageo | RC0603FR-07100KL | 100k | 0603 | 0.1 W | MOSFET gate pull-down | Verify lifecycle, authorized source, stock, and current datasheet before build
TP1 | 1 | Keystone Electronics | 5000 | 3V3 | TestPoint_Loop | 3 A | 3.3 V test point | Verify lifecycle, authorized source, stock, and current datasheet before build
TP2 | 1 | Keystone Electronics | 5000 | GND | TestPoint_Loop | 3 A | ground test point | Verify lifecycle, authorized source, stock, and current datasheet before build
TP3 | 1 | Keystone Electronics | 5000 | SDA | TestPoint_Loop | 3 A | I2C data test point | Verify lifecycle, authorized source, stock, and current datasheet before build
TP4 | 1 | Keystone Electronics | 5000 | SCL | TestPoint_Loop | 3 A | I2C clock test point | Verify lifecycle, authorized source, stock, and current datasheet before build
TP5 | 1 | Keystone Electronics | 5000 | RS485_A | TestPoint_Loop | 3 A | RS-485 A test point | Verify lifecycle, authorized source, stock, and current datasheet before build
TP6 | 1 | Keystone Electronics | 5000 | RS485_B | TestPoint_Loop | 3 A | RS-485 B test point | Verify lifecycle, authorized source, stock, and current datasheet before build
U1 | 1 | Espressif Systems | ESP32-WROOM-32E-N4 | ESP32-WROOM-32E | Module_ESP32-WROOM-32 | 3.0 to 3.6 V | edge gateway MCU and radio | Verify lifecycle, authorized source, stock, and current datasheet before build
U2 | 1 | Texas Instruments | TMP117MAIDRVR | TMP117M | WSON-6-2x2mm | -55 to 150 deg C | digital temperature sensor | Verify lifecycle, authorized source, stock, and current datasheet before build
U3 | 1 | Texas Instruments | INA219AIDCNR | INA219A | SOT-23-8 | 26 V common mode | high-side DC current monitor | Verify lifecycle, authorized source, stock, and current datasheet before build
U4 | 1 | Analog Devices | ADXL345BCCZ-RL7 | ADXL345 | LGA-14-3x5mm | 2.0 to 3.6 V | 3-axis vibration sensor | Verify lifecycle, authorized source, stock, and current datasheet before build
U5 | 1 | Analog Devices | MAX3485ESA+ | MAX3485 | SOIC-8 | 3.0 to 3.6 V | 3.3 V half-duplex RS-485 transceiver | Verify lifecycle, authorized source, stock, and current datasheet before build
U6 | 1 | Diodes Incorporated | AP2112K-3.3TRG1 | AP2112K-3.3 | SOT-23-5 | 600 mA | 3.3 V logic regulator | Verify lifecycle, authorized source, stock, and current datasheet before build

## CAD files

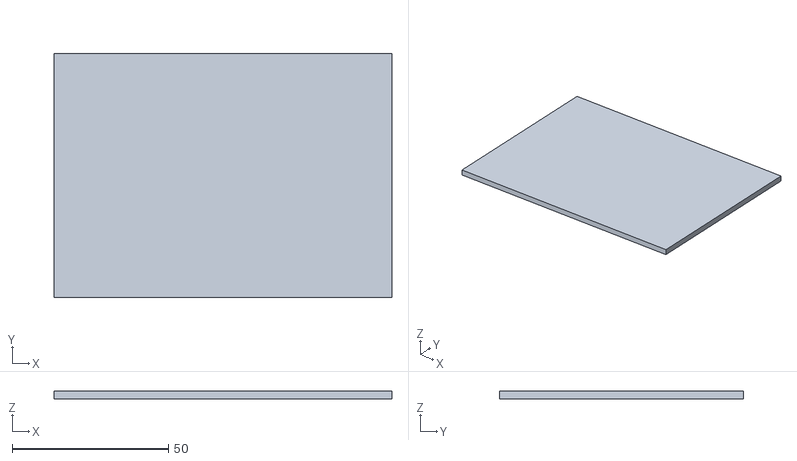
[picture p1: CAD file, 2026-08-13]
hardware/enclosure/iiot-enclosure-lid.stl
108.0 x 78.0 x 2.40

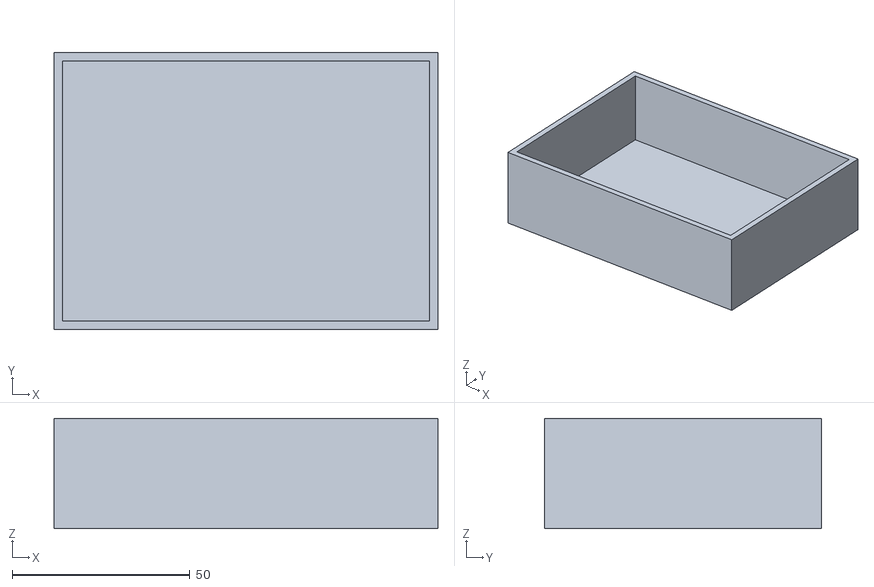
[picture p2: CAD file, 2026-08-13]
hardware/enclosure/iiot-enclosure-base.stl
108.0 x 78.0 x 31.0

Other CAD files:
hardware/enclosure/iiot-enclosure-assembly.step
hardware/3d-models/G5V-1-envelope.step
hardware/fabrication/iiot-monitor-board-engineering-envelope.step
hardware/3d-models/ESP32-WROOM-32E-envelope.step

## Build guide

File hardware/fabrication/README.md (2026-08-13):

# NOT RELEASED FOR FABRICATION

Every file in this directory is a review artifact for revision
`A0-UNVERIFIED`. `fabrication-status.json` is authoritative:

- board routing is incomplete;
- ERC and DRC were not run because KiCad is unavailable;
- copper Gerbers intentionally contain no production routing;
- the STEP assembly uses project-authored component envelopes;
- no PCB order or assembly is approved.

Do not upload this directory to a fabricator. The expected future release set is
BOM, centroid/position CSV, top/bottom copper, solder masks, silkscreen, board
outline, plated/non-plated drills, schematic PDF, and component-accurate board
STEP, all regenerated by KiCad after the documented gates pass.

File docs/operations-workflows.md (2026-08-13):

# Authenticated operations workflows

All examples are for the local, simulated, extra-low-voltage demonstrator. The
relay command is not a safety function and does not authorize connection to
mains voltage or uncontrolled machinery.

## Roles and audit behavior

Authenticated operators can view fleet, telemetry, alarms, calibrations,
maintenance, thresholds, commands, and bounded CSV exports. Administrators are
required to change thresholds, create calibrations, and issue relay commands.
Alarm acknowledgements, calibration changes, maintenance changes, threshold
updates, command issuance, and device acknowledgements create durable audit
events.

## Live dashboard connection

The dashboard posts credentials to `/api/auth/login`. Its backend-for-frontend
exchanges them for an OAuth access token and returns an `iiot_session` cookie
with `HttpOnly`, `SameSite=Strict`, and a bounded lifetime. Browser JavaScript
therefore opens the socket without handling the token:

```js
const socket = new WebSocket("ws://localhost:8000/api/v1/ws");
socket.addEventListener("message", (event) => {
  const update = JSON.parse(event.data);
  console.log(update.type, update);
});
```

The API requires an exact browser Origin allow-list match before accepting the
cookie-authenticated handshake. It emits `telemetry`, `health`,
`alarm_acknowledged`, and `command_ack` events. All dashboard REST operations
also pass through an allow-listed same-origin proxy, so the access token is
absent from browser-readable storage and URLs.

## Command-line WebSocket connection

A non-browser diagnostic client can obtain a token directly and offer the
subprotocol pair `bearer, <JWT>`. The server negotiates only `bearer`; the JWT is
never placed in the URL. This flow is retained for deterministic integration
tests and operational diagnostics, not for the dashboard.

## Alarm and threshold behavior

Each metric has warning and critical thresholds. A reading opens or updates one
active alarm per device and metric. The alarm clears only after the value drops
below the warning threshold by the configured hysteresis percentage. An
acknowledgement records the operator but does not clear an active condition.

## Relay behavior

The API first writes the command and audit event, then publishes a short-lived,
device-addressed MQTT command. The simulated gateway validates identity,
expiry, command kind, and bounded parameters. It starts OFF, reports the applied
state, automatically returns to OFF after an ON timeout, and forces OFF on
disconnect or shutdown. The API command record is authoritative for delivery
status; an HTTP `202` alone is not proof that a device applied a command.

## CSV export boundaries

Exports require authentication, one allow-listed metric, at most 31 days, and
at most 10,000 rows. Text fields that could be interpreted as spreadsheet
formulas are prefixed before serialization. Timestamps are UTC ISO-8601 values.

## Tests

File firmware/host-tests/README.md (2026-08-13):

# Firmware host tests

These tests compile the exact dependency-free C core used by the ESP32 and STM32
targets. They cover configuration validation/migration/integrity, measurement
aggregation, threshold hysteresis, deterministic queue overflow and replay
order, MQTT topics, contract serialization, reconnect backoff, Modbus register
encoding, CRC/address handling, exceptions, configuration writes, and golden
RTU frames.

```sh
cmake -S firmware/host-tests -B firmware/host-tests/build
cmake --build firmware/host-tests/build --parallel
ctest --test-dir firmware/host-tests/build --output-on-failure
```

Warnings are errors. The local macOS compiler is currently blocked before
invocation by an unaccepted system Xcode license, so a local pass is not
claimed; the same commands are intended for the Linux CI job.

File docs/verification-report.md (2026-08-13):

# Verification report

Verification date baseline: 2026-08-13 (earlier live rows retained from 2026-08-11)
Environment: macOS workspace, hardware not supplied  
Repository commit: recorded after each milestone

| Area | Command or inspection | Result | Level | Evidence / reason |
| --- | --- | --- | --- | --- |
| Identity inputs | `rg` placeholder scan | PASS | N/A | No unresolved configured identity tokens found |
| Contracts | `.venv/bin/pytest tests/test_contracts.py -q` | PASS (8 tests) | SIMULATED | Seven positive examples and one clock-sync negative case |
| Contract quality | Ruff and Mypy | PASS | SIMULATED | Format/lint clean; strict typing clean for `contracts` |
| Python services | Ruff, strict Mypy, Pytest with branch coverage | PASS (48 tests; 77.90% coverage) | SIMULATED | 50 typed source files; 70% gate; contracts, auth, ingestion, operations, migration, WebSocket, Modbus, simulator, anomaly, gateway, and hardware static paths |
| Database migrations | Alembic SQLite upgrade/downgrade test and PostgreSQL startup migrations | PASS | SIMULATED | SQLite upgrade/downgrade and the fresh PostgreSQL Compose startup both pass through current head `20260811_0004` |
| Software ingestion slice | Compose health + deterministic 12-message MQTT publish + authenticated API query | PASS | SIMULATED | PostgreSQL, Mosquitto, API, and ingestor healthy; API returned 12 rows, newest sequence 10011 |
| Idempotent replay | Republish identical 12-message batch | PASS | SIMULATED | Ingestor logged all messages as duplicate; API count remained 12 |
| Live operations | Authenticated WebSocket + unique MQTT telemetry + threshold alarm | PASS | SIMULATED | Sequence 320002 arrived live; temperature alarm opened; retained health exposed RSSI, queue, reset, and Modbus state |
| Relay command workflow | Authenticated API command through MQTT acknowledgement | PASS | SIMULATED | Relay ON and OFF both reached `completed` with `RELAY_ON` / `RELAY_OFF`; durable audit records persisted |
| WebSocket credential handling | Bearer subprotocol handshake and access-log inspection | PASS | SIMULATED | Negotiated `bearer`; access log contained `/api/v1/ws` with no token in the URL |
| Dashboard source quality | ESLint, TypeScript, Vitest, and npm audit | PASS (6 tests; audit 0 vulnerabilities) | SIMULATED | Responsive components, bounded/gapped chart behavior, status text, and loopback-origin policy passed locally and in hosted CI |
| Dashboard production build | `npm --prefix web run build` and container build | PASS | SIMULATED | Source and production-container builds pass with checksum-tracked self-hosted Geist; the rebuilt Compose image reached health locally and in hosted CI |
| Dashboard browser smoke test | Sign-in, fleet SSR/BFF data, console, and viewport inspection | PARTIAL PASS | SIMULATED | Login and seeded fleet rendered with no error overlay, console error, or horizontal overflow |
| Dashboard browser live channel | Cookie-authenticated telemetry and command flow after loopback normalization | PASS | SIMULATED | Local desktop/mobile Playwright passed, followed by a 20-run concurrent stress pass; hosted CI then passed both profiles with the MQTT acknowledgement recorded as `RELAY_OFF` |
| Aggregate Make wrapper | `make check` | BLOCKED | N/A | Host Xcode license is unaccepted; Ruff, Mypy, Pytest, and Compose config commands from the target were each run directly and passed |
| ESP32 shared core | CMake build and CTest | BLOCKED | SIMULATED | Tests cover config/CRC/migration, calculations, hysteresis, queue loss/replay, serialization, topics, and backoff; system compiler is blocked by the unaccepted Xcode license and CMake is absent |
| ESP32 target | ESP-IDF 6.0.2 build and size report | Not run | SIMULATED | ESP-IDF toolchain is not installed in the environment; no build pass or size is claimed |
| ESP32 Wokwi | Deterministic normal/fault/reconnect/replay scenarios | Not run | SIMULATED | Editable project and driver-boundary adapter exist; Wokwi runner unavailable, so no serial capture is fabricated |
| Modbus host simulator | Ruff, strict Mypy, Pytest | PASS (5 tests) | SIMULATED | Exact golden request/response, timeout, bad response CRC, illegal address, stale registers, request CRC rejection, and PTY round trip |
| STM32 shared C protocol | CMake build and golden CTest | BLOCKED | SIMULATED | Compiler/CMake limitation is shared with the ESP32 C tests; authored byte fixtures match the executed Python suite, but no C pass is claimed |
| STM32 target and Wokwi | ARM build, size, timer/ADC/UART/watchdog scenarios | Not run | SIMULATED | ARM GCC, STM32CubeF1 checkout, and Wokwi runner unavailable; IWDG and backup-domain simulator gaps documented |
| Anomaly feature/model quality | Ruff, strict Mypy, Pytest | PASS (8 tests) | SIMULATED | Causal gap-bounded features, healthy gates, deterministic seed, score semantics, reasons, checksum/schema/staleness rejection, registry, scoring, and sensor-rule fallback |
| Anomaly synthetic evaluation | `python -m services.anomaly_worker.main evaluate-demo` | PASS | SIMULATED | Versioned report: model F1 0.7293/FPR 0.0545; deterministic F1 0.6787/FPR 0.0; `field_performance_claimed=false` |
| Anomaly Compose process | Migration, health, DB backlog scoring, dashboard model state | PARTIAL PASS | SIMULATED | Current migration and anomaly-worker health pass in local and hosted Compose; source integration tests pass, while the hosted happy path does not separately assert a new backlog score |
| Hardware source consistency | Generator check and Pytest | PASS (5 tests) | SIMULATED | Canonical design/BOM refs, required protection roles, model checksums, editable-source presence, and fabrication-release guard pass |
| Hardware placement renders | Source-derived SVG inspection | PARTIAL | SIMULATED | SVG board/enclosure review renders are present; local image viewer could not rasterize SVG, so no visual-pass claim is made |
| Hardware KiCad ERC/DRC/routing | KiCad 10.0.4 | BLOCKED | SIMULATED | Tool unavailable; legacy schematic requires KiCad 10 migration, review footprints require datasheet validation, board is intentionally un-routed, and reports say NOT RUN |
| Hardware fabrication/3D outputs | Static generator and provenance inspection | PARTIAL | SIMULATED | BOM, position, outline/drill review files, envelope STEP/STL, checksums, and FreeCAD macro exist; copper release, schematic PDF, component-accurate board STEP, and FreeCAD execution are not claimed |
| Bilingual engineering PDFs | invariant build, pypdf/pdfplumber inspection, Poppler render, contact-sheet review | PASS | SIMULATED | English 18 pages, Persian 18 pages, hardware review 4 pages; embedded fonts, text, page size/count, non-blank render, RTL/Latin samples, and every-page contact sheets passed |
| Dependency/license inventory | `scripts/check_dependency_licenses.py` | PASS (602 rows) | N/A | Exact Python runtime/CI and npm locks have non-missing license metadata; reviewed dispositions and strong-copyleft guard are current |
| Public repository hygiene | `scripts/check_repository_hygiene.py` | PASS | N/A | All eligible public text files passed identity, placeholder, machine-path, local-link, source-SPDX, action-pin, required-artifact, and dashboard-font checksum checks |
| GitHub workflow source and hosted execution | YAML policy checks, CI, and security workflows | PASS | N/A | Three YAML files parse and all actions use full commit SHAs; hosted [CI run 31684474191](https://github.com/aminzoroufi/intelligent-industrial-iot-monitoring-platform/actions/runs/31684474191) and [security run 31684474179](https://github.com/aminzoroufi/intelligent-industrial-iot-monitoring-platform/actions/runs/31684474179) passed on commit `bfdd487` |
| GitHub publication | `gh auth status`, `git push`, remote metadata inspection | PASS | N/A | The configured public repository exists under `aminzoroufi`; `main` was pushed without force, set as the remote default branch, and the requested description and topics were verified. Hosted CI status is reported separately after publication. |
| Bench | Physical procedure | Not run | BENCH-VERIFIED | No physical evidence supplied |
| Field | Validation protocol | Not run | FIELD-VALIDATED | Outside current evidence |

Only an executed pass with retained output may replace a pending or not-run
entry. Hardware-only checks are not counted as passing when skipped.

## Executed backend vertical-slice commands

```sh
IIOT_ENV_FILE=.env.example docker compose --env-file .env.example up --build -d
.venv/bin/python -m simulator.telemetry_generator.main normal \
  --count 12 --interval-s 0 --sequence-start 10000 --session-id compose-e2e
.venv/bin/pytest tests services simulator -q
.venv/bin/pytest tests services simulator -q --cov=contracts --cov=services \
  --cov=simulator --cov-branch --cov-fail-under=70
.venv/bin/ruff check contracts services simulator tests conftest.py
.venv/bin/mypy contracts services simulator
npm --prefix web run lint
npm --prefix web run typecheck
npm --prefix web test
npm --prefix web audit
npm --prefix web run build
npm --prefix web run test:e2e
.venv/bin/python scripts/compose_smoke.py
.venv/bin/python -m services.anomaly_worker.main evaluate-demo
.venv/bin/python scripts/generate_hardware_artifacts.py --check
.venv/bin/python scripts/check_dependency_licenses.py
.venv/bin/python scripts/check_repository_hygiene.py
python scripts/build_reports.py
python scripts/verify_reports.py
```

The same simulator command was executed twice. The first execution inserted 12
rows. The second produced 12 duplicate statuses and no additional rows.

The operations verification used the OAuth token endpoint, then opened
`/api/v1/ws` with the `bearer, <JWT>` WebSocket subprotocol pair. It published a
unique rising-temperature envelope, observed the live notification and active
alarm, issued relay ON and OFF requests, and matched both command IDs to device
acknowledgements. No physical relay was claimed or tested.

The dashboard production image was started with the same Compose stack. Browser
tests signed in through the same-origin backend-for-frontend, rendered the
seeded fleet, observed live telemetry, issued the simulated Force OFF command,
and matched the persisted `RELAY_OFF` acknowledgement. Loopback origins are
normalized without weakening protocol or port checks, and an acknowledgement
that outruns the HTTP 202 response is reconciled from the authoritative audit.
The final path passed locally, in a 20-run concurrent stress test, and in hosted
desktop/mobile Playwright jobs.

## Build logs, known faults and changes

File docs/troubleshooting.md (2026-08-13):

# Troubleshooting

## Make exits before running a target on macOS

An unaccepted system Xcode license can prevent `/usr/bin/make` from starting.
Review and accept system licenses yourself if appropriate, or use the equivalent
Docker Compose and Python commands documented in `docs/local-development.md`.
Project setup does not require changing a system-wide agreement.

## Occupied ports

The demo binds only loopback ports 3000, 8000, 1883, and 5432. Stop the conflicting
local service or change the host-side port in `compose.yaml`; do not alter the
container-side service addresses.

## Migration or API startup failure

Inspect `docker compose logs api postgres`. The API runs `alembic upgrade head`
before seeding and serving. A changed database password does not modify an
already initialized volume; use the bounded `make reset-demo` only when losing
local demo data is intended.

## MQTT messages are not persisted

Check that Mosquitto and `mqtt-ingestor` are healthy, then inspect their logs.
The worker rejects payloads over 16 KiB, invalid JSON/schema, invalid topics,
and topic/payload identity mismatches. Duplicate message IDs are accepted as
idempotent duplicates rather than inserted again.

## API returns 401

Obtain a bearer token from `/api/v1/auth/token` using form-encoded OAuth2
password fields. Tokens are audience-bound, expire after 30 minutes by default,
and are invalid after changing `IIOT_JWT_SECRET`.

## Missing WebSocket data

For the dashboard, sign out and back in to refresh the HttpOnly session cookie,
and open the dashboard with a host listed exactly in `IIOT_CORS_ORIGINS`. The
configured WebSocket URL and dashboard URL must use the same hostname so the
host-only cookie is sent; the dashboard normalizes the common local loopback
names. For a non-browser diagnostic client, offer `bearer` and the access token
as subprotocols in that order. Query-string tokens are intentionally rejected.
Then inspect API logs for listener reconnect warnings and ingestor logs for the
corresponding persisted message.

## Missing anomaly model

Open `GET /api/v1/devices/{device_id}/anomaly-model` or the detector-comparison
dashboard. `MODEL_NOT_READY` means no reviewed training window has been
registered; it is not silently replaced with a global model. Confirm the window
has at least `IIOT_ANOMALY_MINIMUM_FEATURE_ROWS` eligible causal rows, no bad
quality or fault flags, and explicit UTC bounds.

For `STALE` or `ERROR`, inspect `docker compose logs anomaly-worker` and the
`error_logs` table. Do not copy downloaded artifacts into `IIOT_MODEL_ROOT`.
Checksum, registry, feature-schema, or scikit-learn version mismatches require a
trusted retrain; deterministic threshold and sensor rules continue meanwhile.

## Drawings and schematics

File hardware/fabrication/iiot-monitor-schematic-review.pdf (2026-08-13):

# CONNECTIVITY REVIEW - NOT KICAD SCHEMATIC PDF - NOT FOR FABRICATION

## J1 5V INPUT

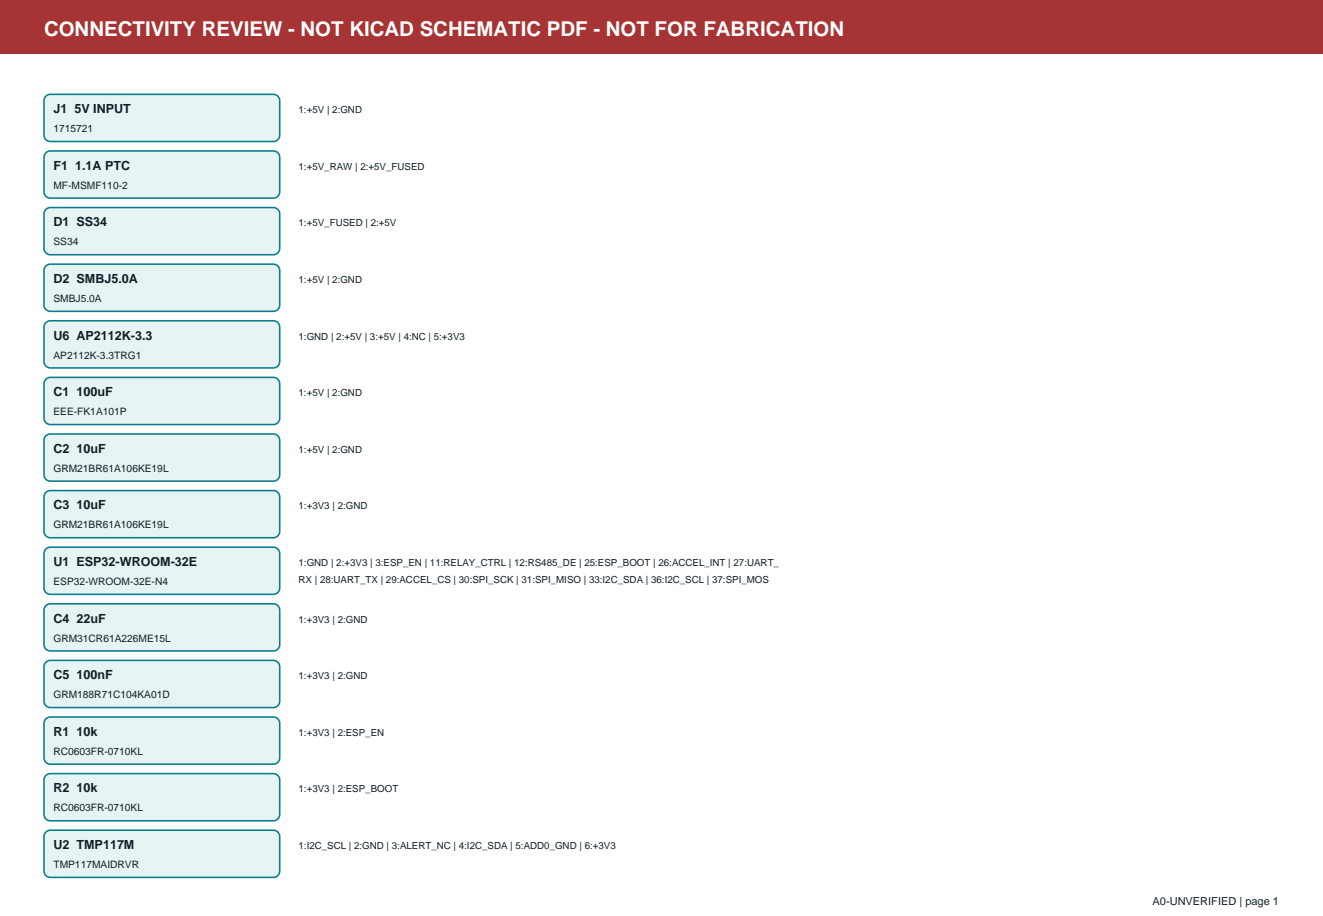
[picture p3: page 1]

## C6 100nF

## U3 INA219A

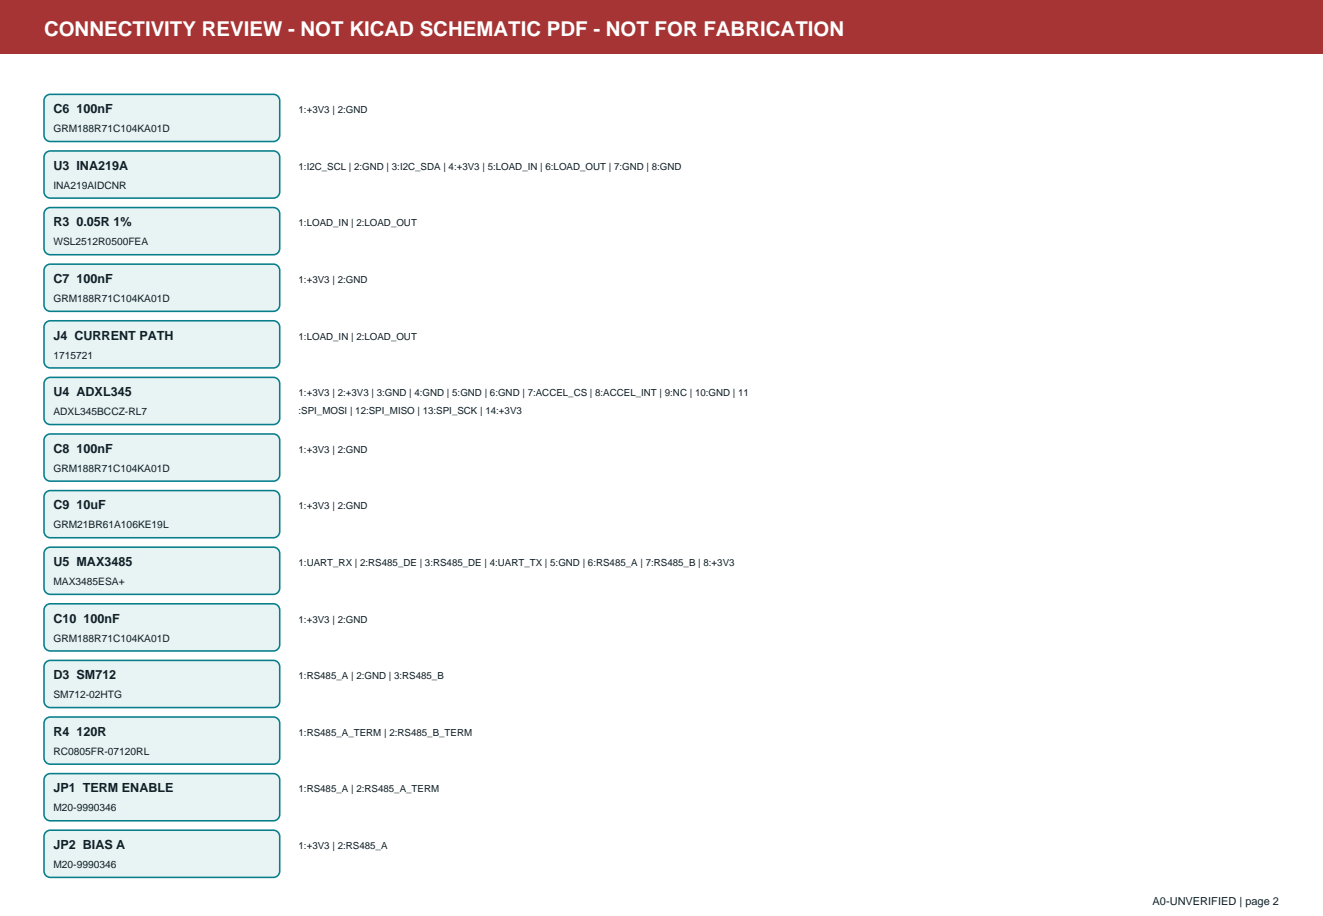
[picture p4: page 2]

1:+3V3 | 2:+3V3 | 3:GND | 4:GND | 5:GND | 6:GND | 7:ACCEL_CS | 8:ACCEL_INT | 9:NC | 10:GND | 11
:SPI_MOSI | 12:SPI_MISO | 13:SPI_SCK | 14:+3V3

## JP3 BIAS B

R5 680R

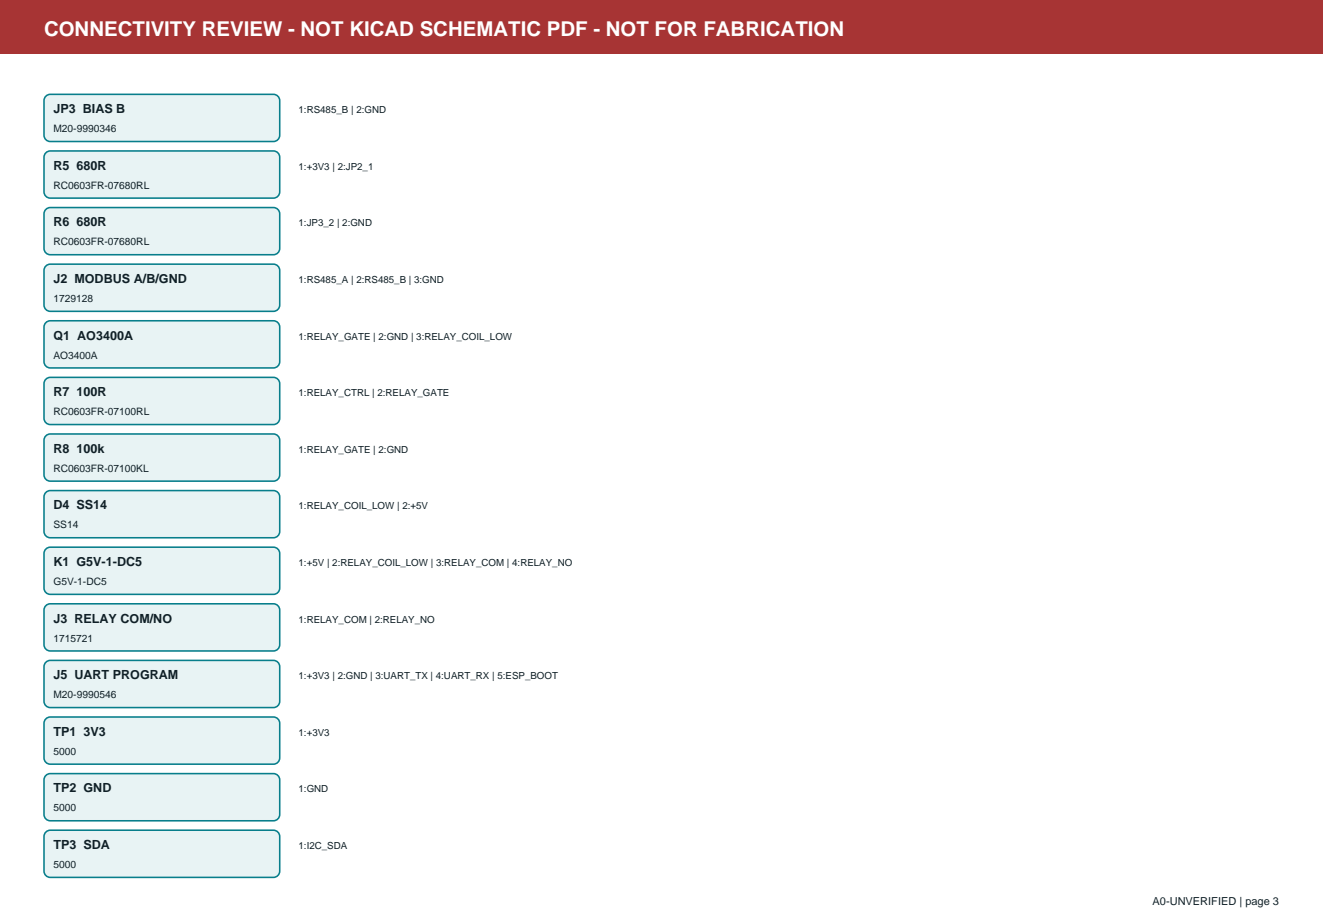
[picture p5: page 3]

## TP4 SCL

5000

1:I2C_SCL

## TP5 RS485_A

5000

1:RS485_A

## TP6 RS485_B

5000

1:RS485_B

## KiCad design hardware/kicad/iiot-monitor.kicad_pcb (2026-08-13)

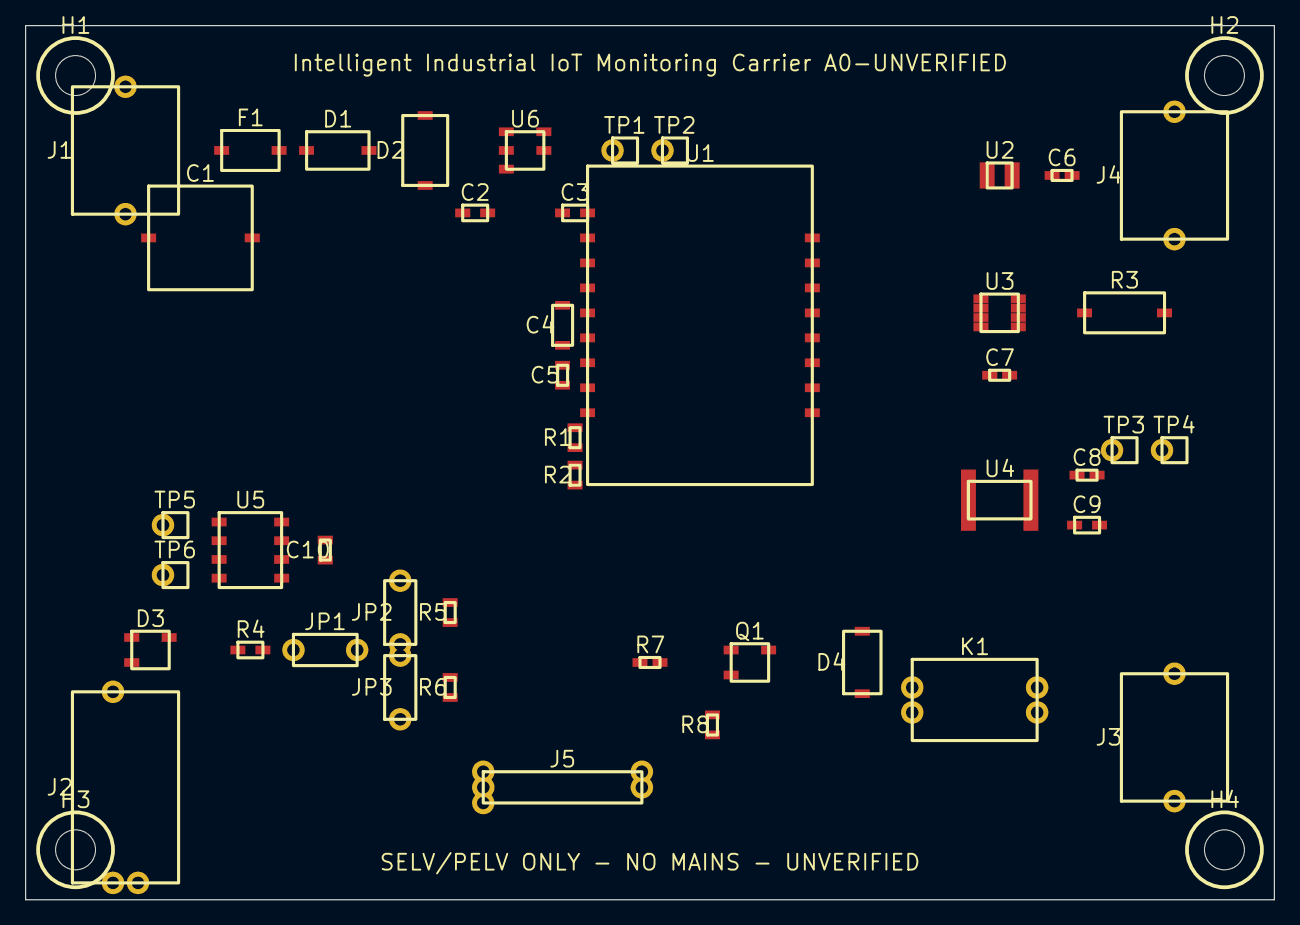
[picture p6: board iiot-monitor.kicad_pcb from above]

Board: 2 copper layers, 100.0 x 70.0 mm, 49 parts (0 on the bottom side), 27 nets, no tracks yet.

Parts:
C1: 100uF; SMD_D8
C2, C3, C9: 10uF; 0805
C4: 22uF; 1206
C5, C6, C7, C8, C10: 100nF; 0603
D1: SS34; SMA
D2: SMBJ5.0A; SMB
D3: SM712; SOT-23
D4: SS14; SMA
F1: 1.1A PTC; 1812
H1, H2, H3, H4: MountingHole_3.2mm_M3
J1: 5V INPUT; TerminalBlock_2P_5.08mm
J2: MODBUS A/B/GND; TerminalBlock_3P_5.08mm
J3: RELAY COM/NO; TerminalBlock_2P_5.08mm
J4: CURRENT PATH; TerminalBlock_2P_5.08mm
J5: UART PROGRAM; PinHeader_1x05_P2.54mm
JP1: TERM ENABLE; PinHeader_1x02_P2.54mm
JP2: BIAS A; PinHeader_1x02_P2.54mm
JP3: BIAS B; PinHeader_1x02_P2.54mm
K1: G5V-1-DC5; Relay_THT_6.5x10mm
Q1: AO3400A; SOT-23
R1, R2: 10k; 0603
R3: 0.05R 1%; 2512
R4: 120R; 0805
R5, R6: 680R; 0603
R7: 100R; 0603
R8: 100k; 0603
TP1: 3V3; TestPoint_Loop
TP2: GND; TestPoint_Loop
TP3: SDA; TestPoint_Loop
TP4: SCL; TestPoint_Loop
TP5: RS485_A; TestPoint_Loop
TP6: RS485_B; TestPoint_Loop
U1: ESP32-WROOM-32E; Module_ESP32-WROOM-32
U2: TMP117M; WSON-6-2x2mm
U3: INA219A; SOT-23-8
U4: ADXL345; LGA-14-3x5mm
U5: MAX3485; SOIC-8
U6: AP2112K-3.3; SOT-23-5

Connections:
+3V3: C3.1, C4.1, C5.1, C6.1, C7.1, C8.1, C9.1, C10.1, J5.1, JP2.1, R1.1, R2.1, R5.1, TP1.1, U1.2, U2.6, U3.4, U4.1, U4.2, U4.14, U5.8, U6.5
+5V: C1.1, C2.1, D1.2, D2.1, D4.2, J1.1, K1.1, U6.2, U6.3
+5V_FUSED: D1.1, F1.2
ACCEL_CS: U1.29, U4.7
ACCEL_INT: U1.26, U4.8
ESP_BOOT: J5.5, R2.2, U1.25
ESP_EN: R1.2, U1.3
GND: C1.2, C2.2, C3.2, C4.2, C5.2, C6.2, C7.2, C8.2, C9.2, C10.2, D2.2, D3.2, J1.2, J2.3, J5.2, JP3.2, Q1.2, R6.2, R8.2, TP2.1, U1.1, U1.38, U2.2, U3.2, U3.7, U3.8, U4.3, U4.4, U4.5, U4.6, U4.10, U5.5, U6.1
I2C_SCL: TP4.1, U1.36, U2.1, U3.1
I2C_SDA: TP3.1, U1.33, U2.4, U3.3
LOAD_IN: J4.1, R3.1, U3.5
LOAD_OUT: J4.2, R3.2, U3.6
NC: U4.9, U6.4
RELAY_COIL_LOW: D4.1, K1.2, Q1.3
RELAY_COM: J3.1, K1.3
RELAY_CTRL: R7.1, U1.11
RELAY_GATE: Q1.1, R7.2, R8.1
RELAY_NO: J3.2, K1.4
RS485_A: D3.1, J2.1, JP1.1, JP2.2, TP5.1, U5.6
RS485_A_TERM: JP1.2, R4.1
RS485_B: D3.3, J2.2, JP3.1, TP6.1, U5.7
RS485_DE: U1.12, U5.2, U5.3
SPI_MISO: U1.31, U4.12
SPI_MOSI: U1.37, U4.11
SPI_SCK: U1.30, U4.13
UART_RX: J5.4, U1.27, U5.1
UART_TX: J5.3, U1.28, U5.4

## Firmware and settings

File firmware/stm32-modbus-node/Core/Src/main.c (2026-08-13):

/*
 * SPDX-FileCopyrightText: 2026 Amin Zoroufi <aminn.zoroufi@gmail.com>
 * SPDX-License-Identifier: LicenseRef-Portfolio-Source-Available
 */
#include "main.h"

#include "modbus_node.h"

#include <stdbool.h>
#include <string.h>

#define CONFIG_FLASH_ADDRESS UINT32_C(0x0800fc00)
#define CONFIG_FLASH_PAGE_SIZE 1024U
#define RX_BUFFER_SIZE 64U
#define FAULT_ADC_RANGE (UINT16_C(1) << 1U)
#define FAULT_SAMPLE_STALE (UINT16_C(1) << 2U)
#define FAULT_UART (UINT16_C(1) << 3U)

ADC_HandleTypeDef hadc1;
TIM_HandleTypeDef htim3;
UART_HandleTypeDef huart2;
IWDG_HandleTypeDef hiwdg;

static modbus_node_t node;
static uint8_t receive_buffer[RX_BUFFER_SIZE];
static volatile uint16_t received_length;
static volatile bool frame_ready;
static volatile bool sample_due;
static uint32_t last_sample_ms;
static uint32_t reset_count;
static uint16_t runtime_faults;

static void SystemClock_Config(void);
static void MX_GPIO_Init(void);
static void MX_ADC1_Init(void);
static void MX_TIM3_Init(void);
static void MX_USART2_UART_Init(void);
static void MX_IWDG_Init(void);

static uint32_t load_reset_count(void) {
#ifdef IIOT_WOKWI
    return 1U;
#else
    HAL_PWR_EnableBkUpAccess();
    __HAL_RCC_BKP_CLK_ENABLE();
    if (BKP->DR1 != UINT16_C(0x4949)) {
        BKP->DR1 = UINT16_C(0x4949);
        BKP->DR2 = 1U;
    } else if (BKP->DR2 != UINT16_MAX) {
        ++BKP->DR2;
    }
    return BKP->DR2;
#endif
}

static bool persist_config(const modbus_node_config_t *config, void *context) {
    (void)context;
    FLASH_EraseInitTypeDef erase = {
        .TypeErase = FLASH_TYPEERASE_PAGES,
        .PageAddress = CONFIG_FLASH_ADDRESS,
        .NbPages = 1U,
    };
    uint32_t page_error = 0U;
    if (HAL_FLASH_Unlock() != HAL_OK) {
        return false;
    }
    bool success = HAL_FLASHEx_Erase(&erase, &page_error) == HAL_OK;
    for (size_t offset = 0U; success && offset < sizeof(*config); offset += 2U) {
        uint16_t value = UINT16_MAX;
        const size_t remaining = sizeof(*config) - offset;
        memcpy(&value, (const uint8_t *)config + offset, remaining >= 2U ? 2U : 1U);
        success = HAL_FLASH_Program(FLASH_TYPEPROGRAM_HALFWORD,
                                    CONFIG_FLASH_ADDRESS + (uint32_t)offset, value) == HAL_OK;
    }
    (void)HAL_FLASH_Lock();
    return success &&
           memcmp((const void *)CONFIG_FLASH_ADDRESS, config, sizeof(*config)) == 0;
}

static void sample_fixture(void) {
    uint16_t adc_raw = 0U;
    modbus_sensor_status_t status = MODBUS_SENSOR_OK;
    uint16_t faults = runtime_faults;
    if (HAL_ADC_Start(&hadc1) != HAL_OK ||
        HAL_ADC_PollForConversion(&hadc1, 2U) != HAL_OK) {
        status = MODBUS_SENSOR_ADC_ERROR;
        faults |= FAULT_ADC_RANGE;
    } else {
        adc_raw = (uint16_t)HAL_ADC_GetValue(&hadc1);
        if (adc_raw < 10U || adc_raw > 4085U) {
            status = MODBUS_SENSOR_OUT_OF_RANGE;
            faults |= FAULT_ADC_RANGE;
        } else {
            faults &= (uint16_t)~FAULT_ADC_RANGE;
        }
    }
    (void)HAL_ADC_Stop(&hadc1);
    const int32_t uncalibrated = 2000 + ((int32_t)adc_raw * 8000) / 4095;
    int32_t calibrated = uncalibrated + node.config.calibration_offset_centi_c;
    calibrated = (calibrated * node.config.calibration_gain_q15) / 32768;
    if (calibrated < -4000 || calibrated > 12500) {
        status = MODBUS_SENSOR_OUT_OF_RANGE;
        faults |= FAULT_ADC_RANGE;
    }
    runtime_faults = faults;
    last_sample_ms = HAL_GetTick();
    modbus_node_set_measurement(&node, adc_raw, (int16_t)calibrated, status, faults,
                                HAL_GetTick(), reset_count);
}

static void transmit_response(const uint8_t *response, size_t length) {
    HAL_GPIO_WritePin(RS485_DE_GPIO_Port, RS485_DE_Pin, GPIO_PIN_SET);
    for (volatile uint32_t delay = 0U; delay < 32U; ++delay) {
        __NOP();
    }
    if (HAL_UART_Transmit(&huart2, response, (uint16_t)length, 50U) != HAL_OK) {
        runtime_faults |= FAULT_UART;
    }
    while (__HAL_UART_GET_FLAG(&huart2, UART_FLAG_TC) == RESET) {
    }
    HAL_GPIO_WritePin(RS485_DE_GPIO_Port, RS485_DE_Pin, GPIO_PIN_RESET);
}

int main(void) {
    HAL_Init();
    SystemClock_Config();
    MX_GPIO_Init();
    MX_ADC1_Init();
    MX_TIM3_Init();
    MX_USART2_UART_Init();
    MX_IWDG_Init();
    (void)HAL_ADCEx_Calibration_Start(&hadc1);
    reset_count = load_reset_count();

    const modbus_node_config_t *stored =
        (const modbus_node_config_t *)CONFIG_FLASH_ADDRESS;
    modbus_node_init(&node, stored, persist_config, NULL);
    if (!modbus_node_config_validate(stored)) {
        (void)persist_config(&node.config, NULL);
    }
    HAL_GPIO_WritePin(RS485_DE_GPIO_Port, RS485_DE_Pin, GPIO_PIN_RESET);
    if (HAL_UARTEx_ReceiveToIdle_IT(&huart2, receive_buffer, sizeof(receive_buffer)) != HAL_OK ||
        HAL_TIM_Base_Start_IT(&htim3) != HAL_OK) {
        Error_Handler();
    }
    sample_due = true;

    for (;;) {
        if (sample_due) {
            sample_due = false;
            sample_fixture();
        }
        if (HAL_GetTick() - last_sample_ms > 500U) {
            runtime_faults |= FAULT_SAMPLE_STALE;
            modbus_node_set_measurement(&node, node.adc_raw, node.temperature_centi_c,
                                        MODBUS_SENSOR_STALE, runtime_faults, HAL_GetTick(),
                                        reset_count);
        } else {
            runtime_faults &= (uint16_t)~FAULT_SAMPLE_STALE;
        }
        if (frame_ready) {
            uint8_t request[RX_BUFFER_SIZE];
            uint16_t length = 0U;
            __disable_irq();
            length = received_length;
            memcpy(request, receive_buffer, length);
            frame_ready = false;
            __enable_irq();
            (void)HAL_UARTEx_ReceiveToIdle_IT(&huart2, receive_buffer,
                                              sizeof(receive_buffer));
            uint8_t response[MODBUS_NODE_MAX_RESPONSE];
            size_t response_length = 0U;
            if (modbus_node_handle_request(&node, request, length, response, sizeof(response),
                                           &response_length) == MODBUS_NODE_RESPONSE) {
                transmit_response(response, response_length);
            }
        }
#ifndef IIOT_WOKWI
        (void)HAL_IWDG_Refresh(&hiwdg);
#endif
        HAL_GPIO_WritePin(STATUS_LED_GPIO_Port, STATUS_LED_Pin,
                          runtime_faults == 0U ? GPIO_PIN_SET : GPIO_PIN_RESET);
    }
}

void HAL_UARTEx_RxEventCallback(UART_HandleTypeDef *uart, uint16_t size) {
    if (uart->Instance != USART2) {
        return;
    }
    if (size == 8U && !frame_ready) {
        received_length = size;
        frame_ready = true;
    } else {
        runtime_faults |= FAULT_UART;
        (void)HAL_UARTEx_ReceiveToIdle_IT(&huart2, receive_buffer,
                                          sizeof(receive_buffer));
    }
}

void HAL_UART_ErrorCallback(UART_HandleTypeDef *uart) {
    if (uart->Instance == USART2) {
        runtime_faults |= FAULT_UART;
        (void)HAL_UARTEx_ReceiveToIdle_IT(&huart2, receive_buffer, sizeof(receive_buffer));
    }
}

void HAL_TIM_PeriodElapsedCallback(TIM_HandleTypeDef *timer) {
    if (timer->Instance == TIM3) {
        sample_due = true;
    }
}

static void SystemClock_Config(void) {
    RCC_OscInitTypeDef oscillator = {
        .OscillatorType = RCC_OSCILLATORTYPE_HSE,
        .HSEState = RCC_HSE_ON,
        .HSEPredivValue = RCC_HSE_PREDIV_DIV1,
        .HSIState = RCC_HSI_ON,
        .PLL.PLLState = RCC_PLL_ON,
        .PLL.PLLSource = RCC_PLLSOURCE_HSE,
        .PLL.PLLMUL = RCC_PLL_MUL9,
    };
    if (HAL_RCC_OscConfig(&oscillator) != HAL_OK) {
        Error_Handler();
    }
    RCC_ClkInitTypeDef clocks = {
        .ClockType = RCC_CLOCKTYPE_HCLK | RCC_CLOCKTYPE_SYSCLK | RCC_CLOCKTYPE_PCLK1 |
                     RCC_CLOCKTYPE_PCLK2,
        .SYSCLKSource = RCC_SYSCLKSOURCE_PLLCLK,
        .AHBCLKDivider = RCC_SYSCLK_DIV1,
        .APB1CLKDivider = RCC_HCLK_DIV2,
        .APB2CLKDivider = RCC_HCLK_DIV1,
    };
    if (HAL_RCC_ClockConfig(&clocks, FLASH_LATENCY_2) != HAL_OK) {
        Error_Handler();
    }
    RCC_PeriphCLKInitTypeDef peripheral_clock = {
        .PeriphClockSelection = RCC_PERIPHCLK_ADC,
        .AdcClockSelection = RCC_ADCPCLK2_DIV6,
    };
    if (HAL_RCCEx_PeriphCLKConfig(&peripheral_clock) != HAL_OK) {
        Error_Handler();
    }
}

static void MX_GPIO_Init(void) {
    __HAL_RCC_GPIOA_CLK_ENABLE();
    __HAL_RCC_GPIOB_CLK_ENABLE();
    __HAL_RCC_GPIOC_CLK_ENABLE();
    HAL_GPIO_WritePin(GPIOB, RS485_DE_Pin, GPIO_PIN_RESET);
    GPIO_InitTypeDef output = {
        .Pin = RS485_DE_Pin,
        .Mode = GPIO_MODE_OUTPUT_PP,
        .Speed = GPIO_SPEED_FREQ_HIGH,
    };
    HAL_GPIO_Init(GPIOB, &output);
    output.Pin = STATUS_LED_Pin;
    output.Speed = GPIO_SPEED_FREQ_LOW;
    HAL_GPIO_Init(GPIOC, &output);
    GPIO_InitTypeDef analog = {.Pin = GPIO_PIN_0, .Mode = GPIO_MODE_ANALOG};
    HAL_GPIO_Init(GPIOA, &analog);
    GPIO_InitTypeDef uart_tx = {
        .Pin = GPIO_PIN_2,
        .Mode = GPIO_MODE_AF_PP,
        .Speed = GPIO_SPEED_FREQ_HIGH,
    };
    HAL_GPIO_Init(GPIOA, &uart_tx);
    GPIO_InitTypeDef uart_rx = {.Pin = GPIO_PIN_3, .Mode = GPIO_MODE_INPUT};
    HAL_GPIO_Init(GPIOA, &uart_rx);
}

static void MX_ADC1_Init(void) {
    __HAL_RCC_ADC1_CLK_ENABLE();
    hadc1.Instance = ADC1;
    hadc1.Init.ScanConvMode = ADC_SCAN_DISABLE;
    hadc1.Init.ContinuousConvMode = DISABLE;
    hadc1.Init.DiscontinuousConvMode = DISABLE;
    hadc1.Init.ExternalTrigConv = ADC_SOFTWARE_START;
    hadc1.Init.DataAlign = ADC_DATAALIGN_RIGHT;
    hadc1.Init.NbrOfConversion = 1U;
    if (HAL_ADC_Init(&hadc1) != HAL_OK) {
        Error_Handler();
    }
    ADC_ChannelConfTypeDef channel = {
        .Channel = ADC_CHANNEL_0,
        .Rank = ADC_REGULAR_RANK_1,
        .SamplingTime = ADC_SAMPLETIME_55CYCLES_5,
    };
    if (HAL_ADC_ConfigChannel(&hadc1, &channel) != HAL_OK) {
        Error_Handler();
    }
}

static void MX_TIM3_Init(void) {
    __HAL_RCC_TIM3_CLK_ENABLE();
    htim3.Instance = TIM3;
    htim3.Init.Prescaler = 7200U - 1U;
    htim3.Init.CounterMode = TIM_COUNTERMODE_UP;
    htim3.Init.Period = 1000U - 1U;
    htim3.Init.ClockDivision = TIM_CLOCKDIVISION_DIV1;
    htim3.Init.AutoReloadPreload = TIM_AUTORELOAD_PRELOAD_DISABLE;
    if (HAL_TIM_Base_Init(&htim3) != HAL_OK) {
        Error_Handler();
    }
    HAL_NVIC_SetPriority(TIM3_IRQn, 3U, 0U);
    HAL_NVIC_EnableIRQ(TIM3_IRQn);
}

static void MX_USART2_UART_Init(void) {
    __HAL_RCC_USART2_CLK_ENABLE();
    huart2.Instance = USART2;
    huart2.Init.BaudRate = 115200U;
    huart2.Init.WordLength = UART_WORDLENGTH_9B;
    huart2.Init.StopBits = UART_STOPBITS_1;
    huart2.Init.Parity = UART_PARITY_EVEN;
    huart2.Init.Mode = UART_MODE_TX_RX;
    huart2.Init.HwFlowCtl = UART_HWCONTROL_NONE;
    huart2.Init.OverSampling = UART_OVERSAMPLING_16;
    if (HAL_UART_Init(&huart2) != HAL_OK) {
        Error_Handler();
    }
    HAL_NVIC_SetPriority(USART2_IRQn, 2U, 0U);
    HAL_NVIC_EnableIRQ(USART2_IRQn);
}

static void MX_IWDG_Init(void) {
#ifndef IIOT_WOKWI
    hiwdg.Instance = IWDG;
    hiwdg.Init.Prescaler = IWDG_PRESCALER_64;
    hiwdg.Init.Reload = 1250U;
    if (HAL_IWDG_Init(&hiwdg) != HAL_OK) {
        Error_Handler();
    }
#endif
}

void Error_Handler(void) {
    __disable_irq();
    HAL_GPIO_WritePin(STATUS_LED_GPIO_Port, STATUS_LED_Pin, GPIO_PIN_RESET);
    for (;;) {
    }
}

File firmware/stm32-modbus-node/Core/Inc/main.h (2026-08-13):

/*
 * SPDX-FileCopyrightText: 2026 Amin Zoroufi <aminn.zoroufi@gmail.com>
 * SPDX-License-Identifier: LicenseRef-Portfolio-Source-Available
 */
#ifndef MAIN_H
#define MAIN_H

#include "stm32f1xx_hal.h"

#define STATUS_LED_Pin GPIO_PIN_13
#define STATUS_LED_GPIO_Port GPIOC
#define RS485_DE_Pin GPIO_PIN_1
#define RS485_DE_GPIO_Port GPIOB

extern ADC_HandleTypeDef hadc1;
extern TIM_HandleTypeDef htim3;
extern UART_HandleTypeDef huart2;
extern IWDG_HandleTypeDef hiwdg;

void Error_Handler(void);

#endif

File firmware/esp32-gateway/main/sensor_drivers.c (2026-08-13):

/*
 * SPDX-FileCopyrightText: 2026 Amin Zoroufi <aminn.zoroufi@gmail.com>
 * SPDX-License-Identifier: LicenseRef-Portfolio-Source-Available
 */
#include "sensor_drivers.h"

#include <math.h>
#include <stdio.h>
#include <string.h>

#include "driver/gpio.h"
#include "driver/uart.h"
#include "esp_check.h"
#include "esp_log.h"
#include "freertos/FreeRTOS.h"
#include "freertos/task.h"

#define I2C_SDA_GPIO 21
#define I2C_SCL_GPIO 22
#define TMP117_ADDRESS 0x48
#define INA219_ADDRESS 0x40
#define SPI_MOSI_GPIO 23
#define SPI_MISO_GPIO 19
#define SPI_CLOCK_GPIO 18
#define ADXL345_CS_GPIO 5
#define ADXL345_DRDY_GPIO 34
#define RS485_UART UART_NUM_2
#define RS485_TX_GPIO 17
#define RS485_RX_GPIO 16
#define RS485_DE_GPIO 25

static const char *const TAG = "sensor";
static char modbus_status[16] = "disabled";

#if !CONFIG_IIOT_SIMULATION
static TaskHandle_t vibration_waiter;
static void IRAM_ATTR vibration_data_ready(void *argument) {
    (void)argument;
    BaseType_t task_woken = pdFALSE;
    if (vibration_waiter != NULL) {
        vTaskNotifyGiveFromISR(vibration_waiter, &task_woken);
        portYIELD_FROM_ISR(task_woken);
    }
}

static esp_err_t i2c_write_register(i2c_master_dev_handle_t device, uint8_t address,
                                    uint16_t value) {
    const uint8_t bytes[] = {address, (uint8_t)(value >> 8U), (uint8_t)value};
    return i2c_master_transmit(device, bytes, sizeof(bytes), 100);
}

static esp_err_t i2c_read_register(i2c_master_dev_handle_t device, uint8_t address,
                                   uint16_t *value) {
    uint8_t bytes[2];
    ESP_RETURN_ON_ERROR(i2c_master_transmit_receive(device, &address, 1U, bytes, sizeof(bytes),
                                                    100),
                        TAG, "i2c register read");
    *value = ((uint16_t)bytes[0] << 8U) | bytes[1];
    return ESP_OK;
}

static esp_err_t adxl_write(sensor_context_t *context, uint8_t address, uint8_t value) {
    uint8_t bytes[] = {address, value};
    spi_transaction_t transaction = {.length = 16U, .tx_buffer = bytes};
    return spi_device_polling_transmit(context->adxl345, &transaction);
}

static esp_err_t adxl_read_xyz(sensor_context_t *context, float *magnitude_mps2) {
    uint8_t transmit[7] = {0x80U | 0x40U | 0x32U};
    uint8_t receive[7] = {0};
    spi_transaction_t transaction = {
        .length = 56U,
        .tx_buffer = transmit,
        .rx_buffer = receive,
    };
    ESP_RETURN_ON_ERROR(spi_device_polling_transmit(context->adxl345, &transaction), TAG,
                        "ADXL345 read");
    const int16_t x = (int16_t)(((uint16_t)receive[2] << 8U) | receive[1]);
    const int16_t y = (int16_t)(((uint16_t)receive[4] << 8U) | receive[3]);
    const int16_t z = (int16_t)(((uint16_t)receive[6] << 8U) | receive[5]);
    const float scale_mps2 = 0.0382459F;
    const float x_value = x * scale_mps2;
    const float y_value = y * scale_mps2;
    const float z_value = z * scale_mps2;
    const float z_dynamic = z_value - copysignf(9.80665F, z_value);
    *magnitude_mps2 =
        sqrtf(x_value * x_value + y_value * y_value + z_dynamic * z_dynamic);
    return ESP_OK;
}

static uint16_t modbus_crc(const uint8_t *bytes, size_t length) {
    uint16_t crc = UINT16_C(0xffff);
    for (size_t index = 0; index < length; ++index) {
        crc ^= bytes[index];
        for (uint8_t bit = 0; bit < 8U; ++bit) {
            crc = (crc & 1U) != 0U ? (crc >> 1U) ^ UINT16_C(0xa001) : crc >> 1U;
        }
    }
    return crc;
}

static void modbus_poll_identity(void) {
    uint8_t request[] = {1U, 3U, 0U, 0U, 0U, 8U, 0U, 0U};
    const uint16_t request_crc = modbus_crc(request, 6U);
    request[6] = (uint8_t)request_crc;
    request[7] = (uint8_t)(request_crc >> 8U);
    (void)uart_flush_input(RS485_UART);
    if (uart_write_bytes(RS485_UART, request, sizeof(request)) != (int)sizeof(request) ||
        uart_wait_tx_done(RS485_UART, pdMS_TO_TICKS(20)) != ESP_OK) {
        (void)snprintf(modbus_status, sizeof(modbus_status), "timeout");
        return;
    }
    uint8_t response[32];
    const int received = uart_read_bytes(RS485_UART, response, sizeof(response),
                                         pdMS_TO_TICKS(80));
    if (received == 0) {
        (void)snprintf(modbus_status, sizeof(modbus_status), "timeout");
        return;
    }
    if (received < 5 || response[0] != 1U) {
        (void)snprintf(modbus_status, sizeof(modbus_status), "stale");
        return;
    }
    if ((response[1] & 0x80U) != 0U) {
        (void)snprintf(modbus_status, sizeof(modbus_status), "exception");
        return;
    }
    const uint16_t actual_crc = modbus_crc(response, (size_t)received - 2U);
    const uint16_t frame_crc = (uint16_t)response[received - 2] |
                               ((uint16_t)response[received - 1] << 8U);
    (void)snprintf(modbus_status, sizeof(modbus_status), "%s",
                   actual_crc == frame_crc ? "ok" : "crc_error");
}
#endif
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

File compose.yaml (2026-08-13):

name: iiot-monitoring-demo

services:
  postgres:
    image: postgres:18.3-bookworm
    environment:
      POSTGRES_DB: ${POSTGRES_DB}
      POSTGRES_USER: ${POSTGRES_USER}
      POSTGRES_PASSWORD: ${POSTGRES_PASSWORD}
    volumes:
      - postgres-data:/var/lib/postgresql
    ports:
      - "127.0.0.1:5432:5432"
    healthcheck:
      test: ["CMD-SHELL", "pg_isready -U $${POSTGRES_USER} -d $${POSTGRES_DB}"]
      interval: 5s
      timeout: 3s
      retries: 12
    restart: unless-stopped

  mosquitto:
    image: eclipse-mosquitto:2.1.2-alpine
    volumes:
      - ./mosquitto/config/mosquitto.conf:/mosquitto/config/mosquitto.conf:ro
      - mosquitto-data:/mosquitto/data
    ports:
      - "127.0.0.1:1883:1883"
    healthcheck:
      test: ["CMD-SHELL", "mosquitto_sub -h 127.0.0.1 -t '$$SYS/broker/version' -C 1 -W 3 >/dev/null"]
      interval: 5s
      timeout: 5s
      retries: 12
    restart: unless-stopped

  api:
    build:
      context: .
      dockerfile: docker/python.Dockerfile
    env_file: ${IIOT_ENV_FILE:-.env}
    command: ["/app/scripts/api-entrypoint.sh"]
    ports:
      - "127.0.0.1:8000:8000"
    depends_on:
      postgres:
        condition: service_healthy
      mosquitto:
        condition: service_healthy
    healthcheck:
      test: ["CMD", "python", "-c", "import urllib.request; urllib.request.urlopen('http://127.0.0.1:8000/healthz', timeout=2)"]
      interval: 5s
      timeout: 3s
      retries: 12
    restart: unless-stopped

  mqtt-ingestor:
    build:
      context: .
      dockerfile: docker/python.Dockerfile
    env_file: ${IIOT_ENV_FILE:-.env}
    command: ["python", "-m", "services.mqtt_ingestor.main"]
    depends_on:
      postgres:
        condition: service_healthy
      mosquitto:
        condition: service_healthy
      api:
        condition: service_healthy
    healthcheck:
      test: ["CMD", "test", "-f", "/app/run/ingestor-ready"]
      interval: 5s
      timeout: 3s
      retries: 12
    restart: unless-stopped

  anomaly-worker:
    build:
      context: .
      dockerfile: docker/python.Dockerfile
    env_file: ${IIOT_ENV_FILE:-.env}
    command: ["python", "-m", "services.anomaly_worker.main", "run"]
    volumes:
      - model-data:/app/data/models
    depends_on:
      postgres:
        condition: service_healthy
      api:
        condition: service_healthy
    healthcheck:
      test: ["CMD", "test", "-f", "/app/run/anomaly-worker-ready"]
      interval: 5s
      timeout: 3s
      retries: 12
    restart: unless-stopped

  simulated-gateway:
    build:
      context: .
      dockerfile: docker/python.Dockerfile
    env_file: ${IIOT_ENV_FILE:-.env}
    command: ["python", "-m", "simulator.gateway_agent"]
    depends_on:
      mosquitto:
        condition: service_healthy
      mqtt-ingestor:
        condition: service_healthy
    healthcheck:
      test: ["CMD", "test", "-f", "/app/run/simulated-gateway-ready"]
      interval: 5s
      timeout: 3s
      retries: 12
    restart: unless-stopped

  web:
    build:
      context: ./web
      args:
        NEXT_PUBLIC_WS_URL: ${NEXT_PUBLIC_WS_URL}
    environment:
      IIOT_API_INTERNAL_URL: http://api:8000
      IIOT_COOKIE_SECURE: ${IIOT_COOKIE_SECURE:-false}
    ports:
      - "127.0.0.1:3000:3000"
    depends_on:
      api:
        condition: service_healthy
    healthcheck:
      test: ["CMD", "wget", "-q", "--spider", "http://127.0.0.1:3000/api/health"]
      interval: 5s
      timeout: 3s
      retries: 12
    restart: unless-stopped

volumes:
  postgres-data:
  mosquitto-data:
  model-data:

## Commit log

2026-08-13 feat: add firmware and hardware reference designs
    [ESP32-WROOM-32E-envelope.step, G5V-1-envelope.step, bom.csv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]
2026-08-13 feat: add operator dashboard and offline demo flows
    [provenance.csv]
2026-08-13 docs: add verified release documentation and CI gates
    [dependency-license-inventory.csv, python-license-policy.csv]
2026-08-13 fix: update vulnerable authentication dependencies
    [dependency-license-inventory.csv]
